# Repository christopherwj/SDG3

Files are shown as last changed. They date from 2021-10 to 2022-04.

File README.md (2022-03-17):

# SDG3 - Powered Speaker System - Happy Tunes

## What should I expect to find in this repo?

Here you can find all of the files related to Team 3's Senior Design Project

This includes: components, datasheets, simulations, source code and more!

## Who is on the team?

| Team Member | Field |
| :--- | :--- |
| Brian Ahlers | Electrical Engineer |
| Abraham Carranza | Computer Engineer |
| Kaitlyn Hamiter | Electrical Engineer |
| Christopher Johnson | Computer Engineer |
| Christopher Kihano  | Computer Engineer |

# Shortcuts

From here on you will find sections detailing different points of Team 3's progress, links to documents and Google Drive directories.

## Senior Design B

### Draw.io Diagrams

- <a href="https://drive.google.com/drive/folders/15kxVudf5h-fhxRucdEdU0__9-gUpvDf6?usp=sharing" target="_blank">Folder Directory</a>

### System Integration Testing
- [Report](https://docs.google.com/document/d/11B_BZgX_fD9LDzKS0TlejT2W-SY3xGZJBUBTwWxWOKQ/edit?usp=sharing)
- [Folder Directory](https://drive.google.com/drive/folders/19PX26QaqbOIaYj3eWc8ziYZd34B6GGTo?usp=sharing)

### Hardware Readiness

- [Report](https://docs.google.com/document/d/16WcHxM67mR_bLpcuLu_cNokmKFwlc5yR9lt_XE9QbTI/edit?usp=sharing)
- [Folder Directory](https://drive.google.com/drive/folders/1j9h-cdcIw9vPNtkVY1A0dE3LBrUp3cXq?usp=sharing)

### Firmware Readiness

- [Report](https://docs.google.com/document/d/1_yuX03Fo50LZgdDcOuhRRBqLqM6c0yxrTySWzuhtTM4/edit?usp=sharing)
- [Folder Directory](https://drive.google.com/drive/folders/1t-pBYhPXyJxyrI6B_gw4tiY_lfn7Jp15?usp=sharing)

### Team Labor Hours

- [Spreadsheet](https://docs.google.com/spreadsheets/d/12QhF0Mqp7NLQ3RBZjQvClqkk2QXMBvIy/edit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)
- [Folder Directory](https://drive.google.com/drive/folders/19Oa_INHHnQHptVcXvDggzD6vj_AUFLqU?usp=sharing)

## Senior Design A

### Draw.io Diagrams
- <a href="https://drive.google.com/drive/folders/15kxVudf5h-fhxRucdEdU0__9-gUpvDf6?usp=sharing" target="_blank">Folder Directory</a>

### System Description, Requirements, Validation

- [Report](https://docs.google.com/document/d/1fnrOCIRyJVDsxmta0oakdDbBKZW54d827w0m6OqQ11Q/edit?usp=sharing)
- [Folder Directory](https://drive.google.com/drive/folders/1NczNZ4O1j9Vx4oX85sgfJVTjJTQ-W3sH?usp=sharing)

### Risk Analysis

- [Report](https://drive.google.com/file/d/1sAik6q6ureZYssgTLGljBEHL8I2Zk15t/view?usp=sharing)
- [Folder Directory](https://drive.google.com/drive/folders/1NczNZ4O1j9Vx4oX85sgfJVTjJTQ-W3sH?usp=sharing)

### Prototype Activity

- [Report](https://drive.google.com/file/d/1stdICW6GUIWn7OOhUiIIFrHZ0VR0cqvk/view?usp=sharing)
- [Folder Directory](https://drive.google.com/drive/folders/1NczNZ4O1j9Vx4oX85sgfJVTjJTQ-W3sH?usp=sharing)

### Critical Design Review

- [Report](https://docs.google.com/presentation/d/1inkozGnM1z5_KCovr3mFNu3Ky42EYbz6ArtEo2gSImo/edit?usp=sharing)
- [Folder Directory](https://drive.google.com/drive/folders/1jWTyNvOkjsP8tEsv12XOycAalzhh8IQb?usp=sharing)

### Final Report

- [Report](https://docs.google.com/document/d/1AqZGzt35glmXr1-TCmBBXokeJKedO_IO3BRvOg3bReY/edit?usp=sharing)
- [Folder Directory](https://drive.google.com/drive/folders/1KJQUjUjOi4YFd6RUpi_W71EKjcTsQYTU?usp=sharing)

### Team Labor Hours

- [Spreadsheet](https://docs.google.com/spreadsheets/d/1y0pf061RG8TchD4RHMXZIr2CGgnv92BU/edit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)
- [Folder Directory](https://drive.google.com/drive/folders/1Dg6yo43kKn5nfYz5vgzlIPh3S6AtKxnr?usp=sharing)

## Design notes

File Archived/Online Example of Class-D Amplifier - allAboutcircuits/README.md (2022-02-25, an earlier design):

# All About Circuits - Class D Amplifier Example

In this directory you can find most, if not all, of the documents from the following webpage

- https://www.allaboutcircuits.com/projects/how-to-build-a-class-d-power-amplifier/

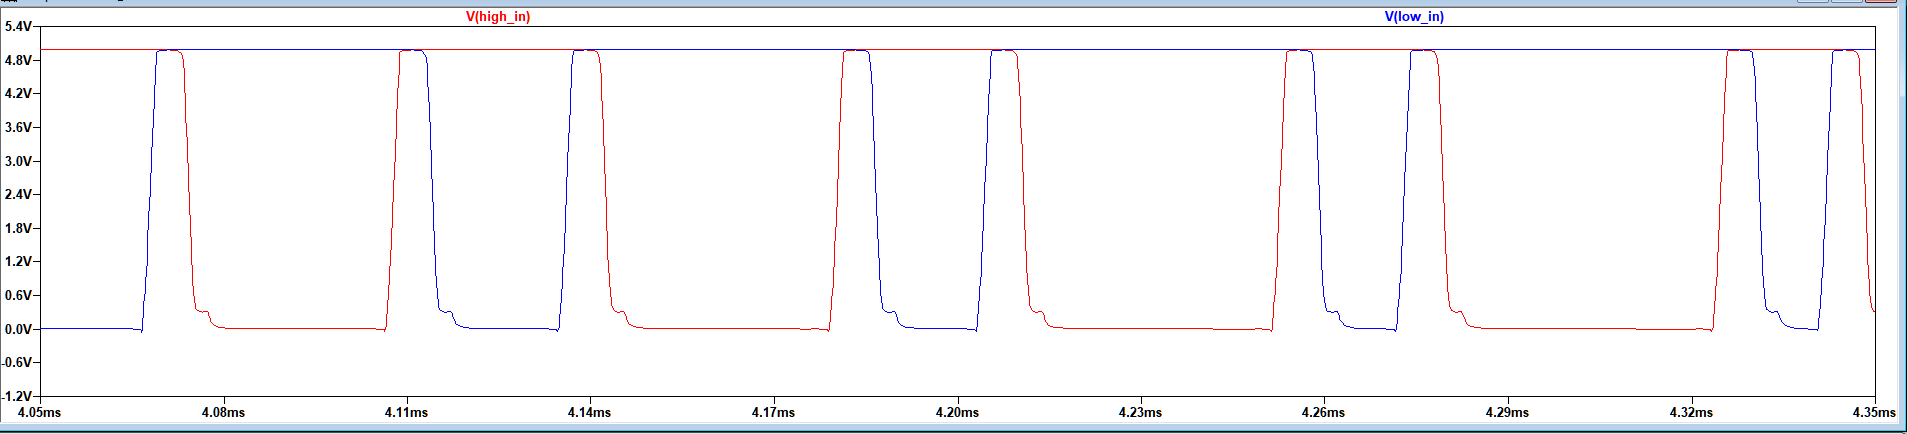
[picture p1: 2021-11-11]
Simulations/Senior Design A/Simulation Outputs/H_L_outLevelShifter.PNG

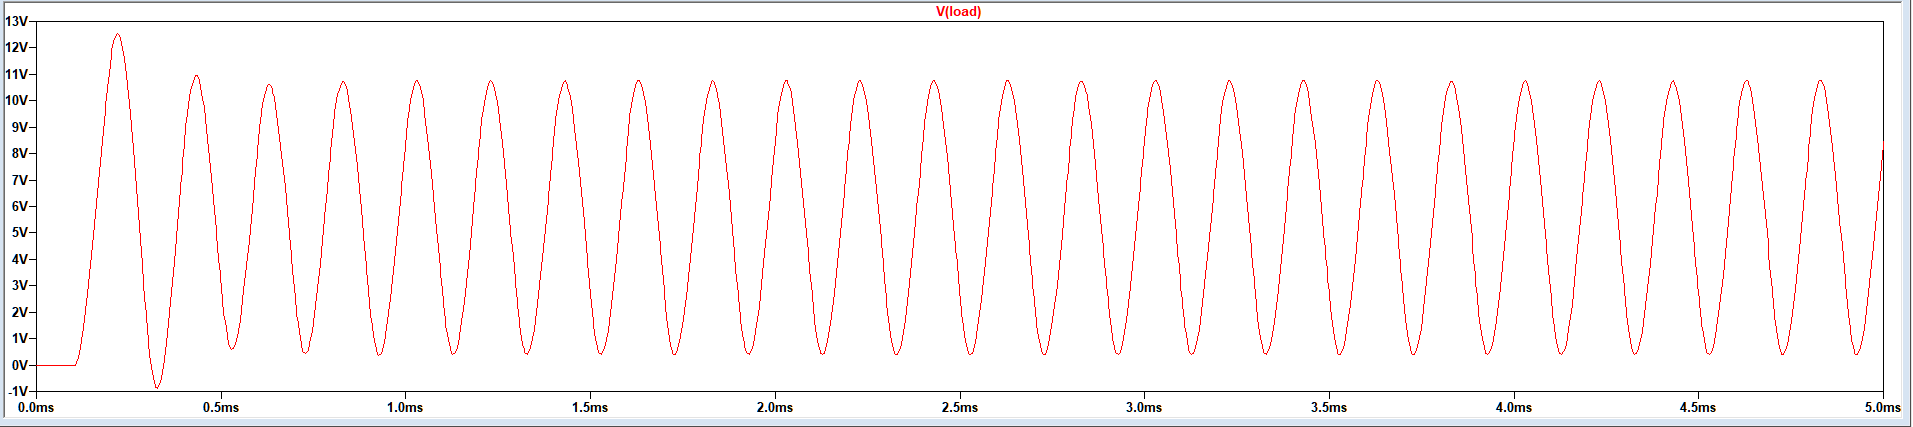
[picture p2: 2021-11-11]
Simulations/Senior Design A/Simulation Outputs/Output.PNG

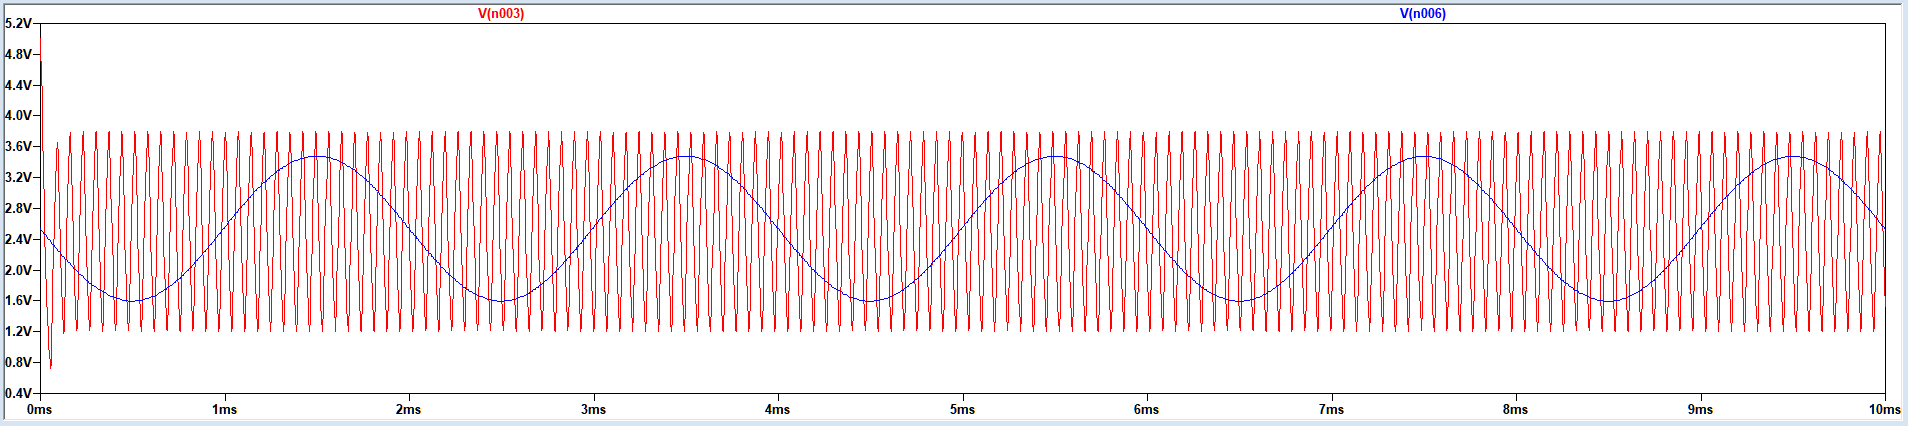
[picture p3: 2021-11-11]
Simulations/Senior Design A/Simulation Outputs/555vsBTAudio.PNG

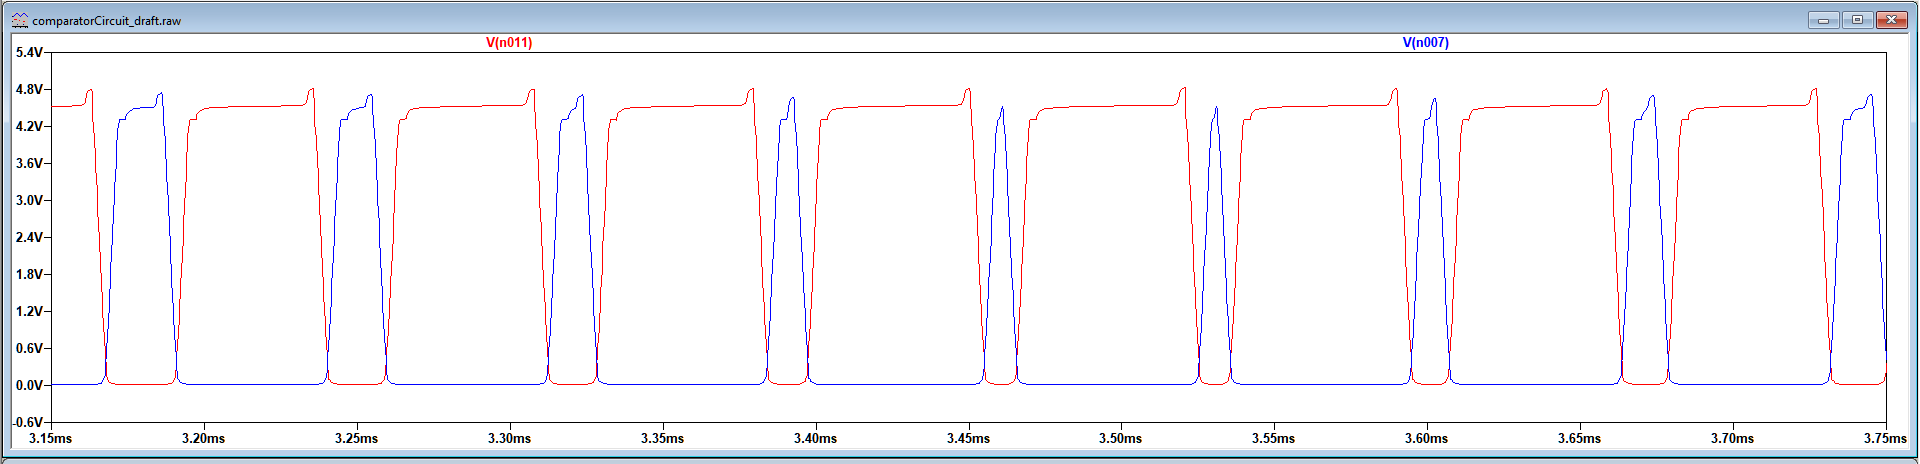
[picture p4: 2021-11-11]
Simulations/Senior Design A/Simulation Outputs/H_L_outofCOMP.PNG

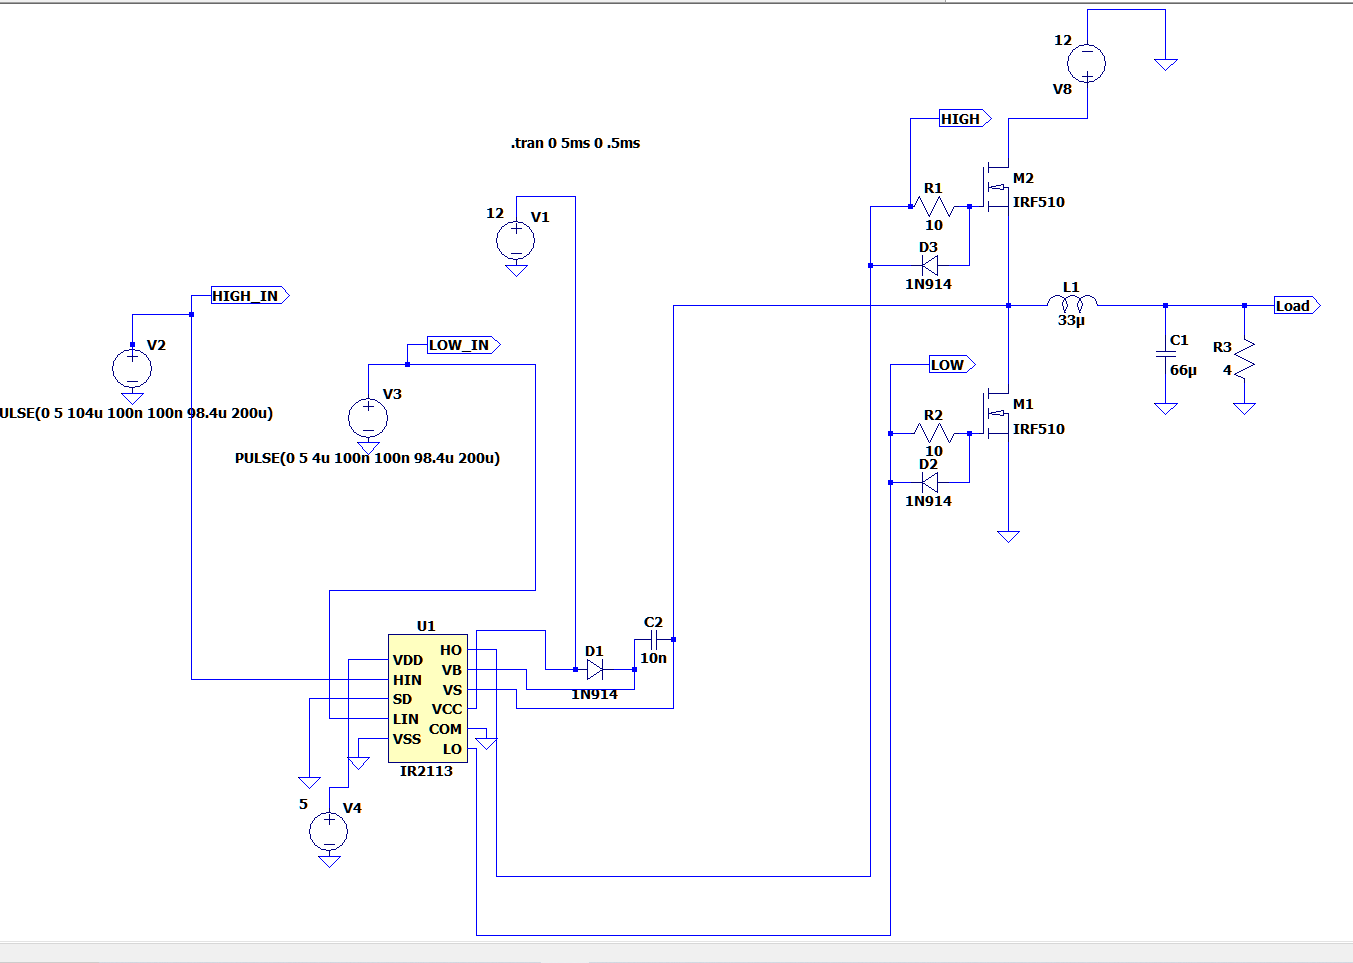
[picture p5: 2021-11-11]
Simulations/Senior Design A/Gate Driver Circuit 2/Gate Driver Circuit Schematic.PNG

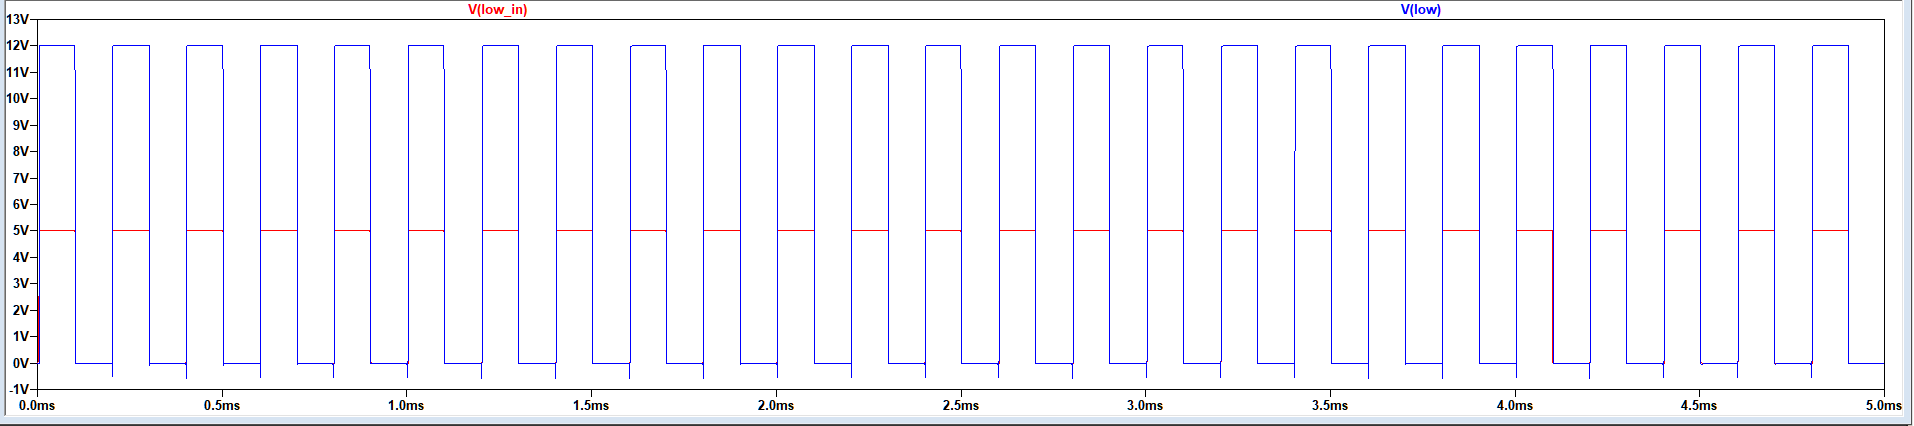
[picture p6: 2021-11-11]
Simulations/Senior Design A/Simulation Outputs/LinvsLout.PNG

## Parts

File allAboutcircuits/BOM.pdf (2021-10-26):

## BOM for Class-D amplifier

Nr. | Designator | Package | Quantity | Designation
1 | Q1,Q2 | TO-92_Inline_Narrow_Oval | 2 | 2N5401
2 | L1 | Inductor_T106-2 | 1 | 22uH
3 | R2 | Resistor_Horizontal_RM10mm | 1 | 2k2
4 | U4 | DIP-14_W7.62mm_LongPads | 1 | IR2110
5 | U3 | TO-220 | 1 | LM7805CT
6 | U2 | DIP-8_W7.62mm_LongPads | 1 | LM393AP
7 | U1 | DIP-8_W7.62mm_LongPads | 1 | LMC555CN
8 | R16,R15 | Resistor_Horizontal_RM10mm | 2 | 10
9 | R14,R13 | Resistor_Horizontal_RM10mm | 2 | 6.8k
10 | R11,R10 | Resistor_Horizontal_RM10mm | 2 | 10k
11 | R9,R8,R7,R6 | Resistor_Horizontal_RM10mm | 4 | 1k
12 | R5,R4 | Resistor_Horizontal_RM15mm | 2 | 1K-2W
13 | R3 | Resistor_Horizontal_RM10mm | 1 | 3.3k
14 | R1 | Resistor_Horizontal_RM10mm | 1 | 330k
15 | R12 | Resistor_Vertical_RM5mm | 1 | 10k
16 | Q5,Q4 | TO-220 | 2 | IRF540N
17 | Q3 | TO-220_Neutral123_Vertical | 1 | BD241C
18 | P1,P2,P3,P4,P5,P6Blade_Connector_6.3mm | 2 | -
19 | F2,F1 | Fuseholder5x20_horiz_open_inline | 2 | 6A
20 | D8,D7,D5,D4 | Diode_DO-35_SOD27_Horizontal_RM10 | 4 | 1N4148
21 | D6 | Diode_DO-41_SOD81_Horizontal_RM10 | 1 | MUR120
22 | D3 | Diode_DO-41_SOD81_Horizontal_RM10 | 1 | zener - 12V
23 | D2,D1 | Diode_DO-41_SOD81_Horizontal_RM10 | 2 | zener - 5V1
24 | C18,C15 | C_Rect_L18_W11_H19_P15 | 2 | 470nF
25 | C17,C13,C12 | C_Rect_L13_W4_P10 | 3 | 220nF
26 | C10 | C_Radial_D5_L11_P2 | 1 | 22uF
27 | C9,C8,C7,C6,C5,C4_Radial_D5_L11_P2 | 6 | 47uF
28 | C3,C1 | C_Rect_L7_W2_P5 | 2 | 1nF
29 | C2 | C_Radial_D5_L11_P2 | 1 | 10uF
30 | C11 | C_0805_HandSoldering | 1 | 100nF
31 | M3 | MountingHole_3.2mm_M3 | 4 | M3 Screw
Resistor values are in Ω. K = 1000. All are 1/4W except R4, R5 (2W)

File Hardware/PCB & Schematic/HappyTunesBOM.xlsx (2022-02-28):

ref | value5 | footprint | datasheet | lib | part | description | names | tstamps6 | tstamp | lib7 | part8 | description9 | docs | fp | field | name10 | num | name11 | type | alias | logical | uri | code | name12 | ref13 | pin
C1 | 0.05 uF | Capacitor_THT:C_Rect_L7.0mm_W2.5mm_P5.00mm | ~ | Device | C | Unpolarized capacitor | / | / | 62162C29
C10 | 22u | Capacitor_THT:C_Rect_L7.0mm_W2.5mm_P5.00mm | ~ | Device | C | Unpolarized capacitor | / | / | 6213681C
C11 | 5.6uF | Capacitor_THT:C_Rect_L7.0mm_W2.5mm_P5.00mm | ~ | Device | C | Unpolarized capacitor | / | / | 61A5E88D
C12 | 5.6uF | Capacitor_THT:C_Rect_L7.0mm_W2.5mm_P5.00mm | ~ | Device | C | Unpolarized capacitor | / | / | 62136830
C13 | 22uF | Capacitor_THT:C_Rect_L7.0mm_W2.5mm_P5.00mm | ~ | Device | C | Unpolarized capacitor | / | / | 621D758A
C2 | 220n | Capacitor_THT:C_Rect_L7.0mm_W2.5mm_P5.00mm | ~ | Device | C | Unpolarized capacitor | / | / | 61AAA34E
C3 | 250 uF | Capacitor_THT:C_Rect_L7.0mm_W2.5mm_P5.00mm | ~ | Device | CP | Polarized capacitor | / | / | 62158BF0
C4 | 220n | Capacitor_THT:C_Rect_L7.0mm_W2.5mm_P5.00mm | ~ | Device | C | Unpolarized capacitor | / | / | 621A181D
C5 | 220n | Capacitor_THT:C_Rect_L7.0mm_W2.5mm_P5.00mm | ~ | Device | C | Unpolarized capacitor | / | / | 621C33C0
C6 | 220n | Capacitor_THT:C_Rect_L7.0mm_W2.5mm_P5.00mm | ~ | Device | C | Unpolarized capacitor | / | / | 621C33D6
C7 | 220u | Capacitor_THT:C_Radial_D8.0mm_H7.0mm_P3.50mm | ~ | Device | CP | Polarized capacitor | / | / | 6210F666
C8 | 220u | Capacitor_THT:C_Radial_D8.0mm_H7.0mm_P3.50mm | ~ | Device | CP | Polarized capacitor | / | / | 62136920
C9 | 22u | Capacitor_THT:C_Rect_L7.0mm_W2.5mm_P5.00mm | ~ | Device | C | Unpolarized capacitor | / | / | 61A5D009
D1 | 1N914 | Diode_THT:D_DO-35_SOD27_P7.62mm_Horizontal | http://www.vishay.com/docs/85622/1n914.pdf | Diode | 1N914 | 100V 0.3A Small Signal Fast Switching Diode, DO-35 | / | / | 62281C4C
D2 | 1N914 | Diode_THT:D_DO-35_SOD27_P7.62mm_Horizontal | http://www.vishay.com/docs/85622/1n914.pdf | Diode | 1N914 | 100V 0.3A Small Signal Fast Switching Diode, DO-35 | / | / | 621C6EB2
D3 | 1N4007 | Diode_THT:D_DO-41_SOD81_P10.16mm_Horizontal | http://www.vishay.com/docs/88503/1n4001.pdf | Diode | 1N4007 | 1000V 1A General Purpose Rectifier Diode, DO-41 | / | / | 61A569FB
D4 | 1N4007 | Diode_THT:D_DO-41_SOD81_P10.16mm_Horizontal | http://www.vishay.com/docs/88503/1n4001.pdf | Diode | 1N4007 | 1000V 1A General Purpose Rectifier Diode, DO-41 | / | / | 621367F4
D5 | 1N4007 | Diode_THT:D_DO-41_SOD81_P10.16mm_Horizontal | http://www.vishay.com/docs/88503/1n4001.pdf | Diode | 1N4007 | 1000V 1A General Purpose Rectifier Diode, DO-41 | / | / | 61A580C3
D6 | 1N4007 | Diode_THT:D_DO-41_SOD81_P10.16mm_Horizontal | http://www.vishay.com/docs/88503/1n4001.pdf | Diode | 1N4007 | 1000V 1A General Purpose Rectifier Diode, DO-41 | / | / | 621367FE
H1 | MountingHole | MountingHole:MountingHole_2.2mm_M2 | ~ | Mechanical | MountingHole | Mounting Hole without connection | / | / | 621DD05A
H2 | MountingHole | MountingHole:MountingHole_2.2mm_M2 | ~ | Mechanical | MountingHole | Mounting Hole without connection | / | / | 621EA6A0
H3 | MountingHole | MountingHole:MountingHole_2.2mm_M2 | ~ | Mechanical | MountingHole | Mounting Hole without connection | / | / | 621DEFD8
H4 | MountingHole | MountingHole:MountingHole_2.2mm_M2 | ~ | Mechanical | MountingHole | Mounting Hole without connection | / | / | 621EB10E
J1 | AudioJack3 | Connector_Audio:Jack_3.5mm_CUI_SJ1-3533NG_Horizontal | ~ | Connector | AudioJack3 | Audio Jack, 3 Poles (Stereo / TRS) | / | / | 623336F4
J10 | TEST_LOW | Connector_Pin:Pin_D1.3mm_L11.0mm | ~ | Connector | Screw_Terminal_01x01 | Generic screw terminal, single row, 01x01, script generated (kicad-library-utils/schlib/autogen/connector/) | / | / | 61F99901
J11 | TEST_HIGH | Connector_Pin:Pin_D1.3mm_L11.0mm | ~ | Connector | Screw_Terminal_01x01 | Generic screw terminal, single row, 01x01, script generated (kicad-library-utils/schlib/autogen/connector/) | / | / | 621368BD
J12 | TEST_LOW | Connector_Pin:Pin_D1.3mm_L11.0mm | ~ | Connector | Screw_Terminal_01x01 | Generic screw terminal, single row, 01x01, script generated (kicad-library-utils/schlib/autogen/connector/) | / | / | 621368C9
J13 | TEST_Return | Connector_Pin:Pin_D1.3mm_L11.0mm | ~ | Connector | Screw_Terminal_01x01 | Generic screw terminal, single row, 01x01, script generated (kicad-library-utils/schlib/autogen/connector/) | / | / | 61F9C69A
J14 | TEST_Return | Connector_Pin:Pin_D1.3mm_L11.0mm | ~ | Connector | Screw_Terminal_01x01 | Generic screw terminal, single row, 01x01, script generated (kicad-library-utils/schlib/autogen/connector/) | / | / | 621368E1
J15 | TEST_OUTPUT | Connector_Pin:Pin_D1.3mm_L11.0mm | ~ | Connector | Screw_Terminal_01x01 | Generic screw terminal, single row, 01x01, script generated (kicad-library-utils/schlib/autogen/connector/) | / | / | 61F9A94A
J16 | TEST_OUTPUT | Connector_Pin:Pin_D1.3mm_L11.0mm | ~ | Connector | Screw_Terminal_01x01 | Generic screw terminal, single row, 01x01, script generated (kicad-library-utils/schlib/autogen/connector/) | / | / | 621368D5
J17 | Speaker | CustomFootprints:ScrewTerm | ~ | Connector | Screw_Terminal_01x02 | Generic screw terminal, single row, 01x02, script generated (kicad-library-utils/schlib/autogen/connector/) | / | / | 621368A6
J2 | BT Module | Connector_PinHeader_2.54mm:PinHeader_1x06_P2.54mm_Vertical | ~ | Connector | Conn_01x06_Female | Generic connector, single row, 01x06, script generated (kicad-library-utils/schlib/autogen/connector/) | / | / | 6237F84A
J3 | COMP_SINGAL | Connector_Pin:Pin_D1.3mm_L11.0mm | ~ | Connector | Screw_Terminal_01x01 | Generic screw terminal, single row, 01x01, script generated (kicad-library-utils/schlib/autogen/connector/) | / | / | 62377881
J4 | COMP_OUT_L | Connector_Pin:Pin_D1.3mm_L11.0mm | ~ | Connector | Screw_Terminal_01x01 | Generic screw terminal, single row, 01x01, script generated (kicad-library-utils/schlib/autogen/connector/) | / | / | 6237E9E9
J5 | COMP_OUT_H | Connector_Pin:Pin_D1.3mm_L11.0mm | ~ | Connector | Screw_Terminal_01x01 | Generic screw terminal, single row, 01x01, script generated (kicad-library-utils/schlib/autogen/connector/) | / | / | 62381A12
J6 | input | CustomFootprints:ScrewTerm | ~ | Connector | Screw_Terminal_01x02 | Generic screw terminal, single row, 01x02, script generated (kicad-library-utils/schlib/autogen/connector/) | / | / | 61AA1413
J7 | output_VCC | CustomFootprints:ScrewTerm | ~ | Connector | Screw_Terminal_01x02 | Generic screw terminal, single row, 01x02, script generated (kicad-library-utils/schlib/autogen/connector/) | / | / | 61AB4357
J8 | output_5V | CustomFootprints:ScrewTerm | ~ | Connector | Screw_Terminal_01x02 | Generic screw terminal, single row, 01x02, script generated (kicad-library-utils/schlib/autogen/connector/) | / | / | 61AB4B41
J9 | TEST_HIGH | Connector_Pin:Pin_D1.3mm_L11.0mm | ~ | Connector | Screw_Terminal_01x01 | Generic screw terminal, single row, 01x01, script generated (kicad-library-utils/schlib/autogen/connector/) | / | / | 61F96EB2
L1 | 45 uH | Inductor_THT:L_CommonMode_Toroid_Vertical_L24.0mm_W16.3mm_Px10.16mm_Py20.32mm_muRATA_5200 | ~ | pspice | INDUCTOR | Inductor symbol for simulation only | / | / | 61A5DF8E
L2 | 45 uH | Inductor_THT:L_CommonMode_Toroid_Vertical_L24.0mm_W16.3mm_Px10.16mm_Py20.32mm_muRATA_5200 | https://www.murata-ps.com/pub/data/magnetics/kmp_3300.pdf | pspice | INDUCTOR | Inductor symbol for simulation only | / | / | 62136826
Q1 | IRF540N | Package_TO_SOT_THT:TO-220-3_Vertical | http://www.irf.com/product-info/datasheets/data/irf540n.pdf | Transistor_FET | IRF540N | 33A Id, 100V Vds, HEXFET N-Channel MOSFET, TO-220 | / | / | 62A0BE19
Q2 | IRF540N | Package_TO_SOT_THT:TO-220-3_Vertical | http://www.irf.com/product-info/datasheets/data/irf540n.pdf | Transistor_FET | IRF540N | 33A Id, 100V Vds, HEXFET N-Channel MOSFET, TO-220 | / | / | 62AE0A06
Q3 | IRF540N | Package_TO_SOT_THT:TO-220-3_Vertical | http://www.irf.com/product-info/datasheets/data/irf540n.pdf | Transistor_FET | IRF540N | 33A Id, 100V Vds, HEXFET N-Channel MOSFET, TO-220 | / | / | 61A7438A
Q4 | IRF540N | Package_TO_SOT_THT:TO-220-3_Vertical | http://www.irf.com/product-info/datasheets/data/irf540n.pdf | Transistor_FET | IRF540N | 33A Id, 100V Vds, HEXFET N-Channel MOSFET, TO-220 | / | / | 61A713D5
Q5 | IRF540N | Package_TO_SOT_THT:TO-220-3_Vertical | http://www.irf.com/product-info/datasheets/data/irf540n.pdf | Transistor_FET | IRF540N | 33A Id, 100V Vds, HEXFET N-Channel MOSFET, TO-220 | / | / | 6213686C
Q6 | IRF540N | Package_TO_SOT_THT:TO-220-3_Vertical | http://www.irf.com/product-info/datasheets/data/irf540n.pdf | Transistor_FET | IRF540N | 33A Id, 100V Vds, HEXFET N-Channel MOSFET, TO-220 | / | / | 621368F0
R1 | 10k | Resistor_THT:R_Axial_DIN0204_L3.6mm_D1.6mm_P7.62mm_Horizontal | ~ | Device | R | Resistor | / | / | 62A0984B
R10 | 1k | Resistor_THT:R_Axial_DIN0204_L3.6mm_D1.6mm_P7.62mm_Horizontal | ~ | Device | R | Resistor | / | / | 62365616
R11 | 10 | Resistor_THT:R_Axial_DIN0204_L3.6mm_D1.6mm_P7.62mm_Horizontal | ~ | Device | R | Resistor | / | / | 61A58DF0
R12 | 10 | Resistor_THT:R_Axial_DIN0204_L3.6mm_D1.6mm_P7.62mm_Horizontal | ~ | Device | R | Resistor | / | / | 62136808
R13 | 10 | Resistor_THT:R_Axial_DIN0204_L3.6mm_D1.6mm_P7.62mm_Horizontal | ~ | Device | R | Resistor | / | / | 61A5A87A
R14 | 10 | Resistor_THT:R_Axial_DIN0204_L3.6mm_D1.6mm_P7.62mm_Horizontal | ~ | Device | R | Resistor | / | / | 62136812
R15 | 10k | Resistor_THT:R_Axial_DIN0204_L3.6mm_D1.6mm_P7.62mm_Horizontal | ~ | Device | R | Resistor | / | / | 621095E5
R16 | 10k | Resistor_THT:R_Axial_DIN0204_L3.6mm_D1.6mm_P7.62mm_Horizontal | ~ | Device | R | Resistor | / | / | 62136905
R17 | 10k | Resistor_THT:R_Axial_DIN0204_L3.6mm_D1.6mm_P7.62mm_Horizontal | ~ | Device | R | Resistor | / | / | 62108A44
R18 | 10k | Resistor_THT:R_Axial_DIN0204_L3.6mm_D1.6mm_P7.62mm_Horizontal | ~ | Device | R | Resistor | / | / | 621368FA
R2 | 10k | Resistor_THT:R_Axial_DIN0204_L3.6mm_D1.6mm_P7.62mm_Horizontal | ~ | Device | R | Resistor | / | / | 6216B860
R3 | 10k | Resistor_THT:R_Axial_DIN0204_L3.6mm_D1.6mm_P7.62mm_Horizontal | ~ | Device | R | Resistor | / | / | 6216AD7A
R4 | 10k | Resistor_THT:R_Axial_DIN0204_L3.6mm_D1.6mm_P7.62mm_Horizontal | ~ | Device | R | Resistor | / | / | 62326AF8
R5 | 10k | Resistor_THT:R_Axial_DIN0204_L3.6mm_D1.6mm_P7.62mm_Horizontal | ~ | Device | R | Resistor | / | / | 623227F2
R6 | 10k | Resistor_THT:R_Axial_DIN0204_L3.6mm_D1.6mm_P7.62mm_Horizontal | ~ | Device | R | Resistor | / | / | 62AB1896
R7 | 10k | Resistor_THT:R_Axial_DIN0204_L3.6mm_D1.6mm_P7.62mm_Horizontal | ~ | Device | R | Resistor | / | / | 62ADFF7C
R8 | 10 | Resistor_THT:R_Axial_DIN0204_L3.6mm_D1.6mm_P7.62mm_Horizontal | ~ | Device | R | Resistor | / | / | 6216F78B
R9 | 10k | Resistor_THT:R_Axial_DIN0204_L3.6mm_D1.6mm_P7.62mm_Horizontal | ~ | Device | R | Resistor | / | / | 62AE0A1B
RV1 | 10k_POT_TRIM_US | Potentiometer_THT:Potentiometer_Alps_RK09K_Single_Horizontal | ~ | Device | R_POT_TRIM_US | Trim-potentiometer, US symbol | / | / | 621F797F
RV2 | 10k_POT_TRIM_US | Potentiometer_THT:Potentiometer_Alps_RK09K_Single_Horizontal | ~ | Device | R_POT_TRIM_US | Trim-potentiometer, US symbol | / | / | 621F56DD
SW1 | SW_SPDT_MSM | Button_Switch_THT:SW_CuK_OS102011MA1QN1_SPDT_Angled | ~ | Switch | SW_SPDT_MSM | Switch, single pole double throw, center OFF position | / | / | 62273C1A
SW2 | SW_Push_DPDT | Button_Switch_THT:SW_CuK_JS202011AQN_DPDT_Angled | ~ | Switch | SW_Push_DPDT | Momentary Switch, dual pole double throw | / | / | 6258EC3B
SW3 | SW_SPDT_MSM | Button_Switch_THT:SW_CuK_OS102011MA1QN1_SPDT_Angled | ~ | Switch | SW_SPDT_MSM | Switch, single pole double throw, center OFF position | / | / | 6237C367
U1 | LM7805_TO220 | Package_TO_SOT_THT:TO-220-3_Vertical | https://www.onsemi.cn/PowerSolutions/document/MC7800-D.PDF | Regulator_Linear | LM7805_TO220 | Positive 1A 35V Linear Regulator, Fixed Output 5V, TO-220 | / | / | 61A50F17
U2 | LM7810_TO220 | Package_TO_SOT_THT:TO-220-3_Vertical | https://www.onsemi.cn/PowerSolutions/document/MC7800-D.PDF | Regulator_Linear | LM7810_TO220 | Positive 1A 35V Linear Regulator, Fixed Output 10V, TO-220 | / | / | 626785CD
U3 | LM386 | Package_DIP:DIP-8_W7.62mm_Socket | http://www.ti.com/lit/ds/symlink/lm386.pdf | Amplifier_Audio | LM386 | Low Voltage Audio Power Amplifier, DIP-8/SOIC-8/SSOP-8 | / | / | 62152F78
U5 | IR2113 | Package_DIP:DIP-14_W7.62mm_Socket | https://www.infineon.com/dgdl/ir2110.pdf?fileId=5546d462533600a4015355c80333167e | Driver_FET | IR2113 | High and Low Side Driver, 600V, 2.0/2.0A, PDIP-14 | / | / | 621367D6
XA1 | Arduino_Due_Shield | Arduino:Arduino_Due_Shield | https://store.arduino.cc/arduino-due | GateDriver-rescue | Arduino_Due_Shield-arduino |  | / | / | 621319E3

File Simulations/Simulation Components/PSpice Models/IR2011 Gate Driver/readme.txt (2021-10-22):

##########################################################################################
## Simulation model of IR2011 Level 1 for SIMetrix version 8.3g or higher
##########################################################################################

--------------------------------------------------------------------------------
1. Changelog
--------------------------------------------------------------------------------
VER    | BY                       | DATE          | OBS                         
--------------------------------------------------------------------------------
01.00  | MA                       | 2020-09-11    | created    (*1)
--------------------------------------------------------------------------------

(*1) 
Simulation model of IR2011 Level 1 for SIMetrix version 8.3g or higher
Template performance : 
  - Static Electrical Characteristics and Dynamic Electrical Characteristics 
    are modeled with the typical values from the datasheet.
  - Temperature effects are not modeled
The following features have been modeled :
  - Switching Characteristics such as propagation delay, peak/mean currents
  - Undervoltage lockout 

--------------------------------------------------------------------------------
2. Supported platform
--------------------------------------------------------------------------------
This model has been successfully tested with the following software:
- SIMetrix 8.3g or newer versions

--------------------------------------------------------------------------------
3. Structure of the delivery package
--------------------------------------------------------------------------------
The delivery package contains the following:

	\Documentation\GettingStarted.pdf         : guidance on how to get started with the attached behavioral model
	\Documentation\Disclaimer.pdf             : Infineon’s model terms of use
	\Model\IR2011.lib                         : model lib file
	\Model\IR2011.sxslb                       : schematic symbol for the lib
	\Model\DEMO_TESTBENCH.sxsch               : demo testbench provided together with the model 
	\Model\IGBT_650V_TRENCHSTOP5_F5_L1.lib    : Infineon's IGBT model
	\Model\IGBT_650V_TRENCHSTOP5_F5_L1.sxslb  : Infineon's IGBT symbol for schematic
	\Model\results                            : some screenshots with the demo testbench and results
	
--------------------------------------------------------------------------------
4. Infineon contact and support
--------------------------------------------------------------------------------
support@infineon.com

--------------------------------------------------------------------------------
5. Disclaimer
--------------------------------------------------------------------------------

INFINEON’S MODEL TERMS OF USE

BY DOWNLOADING AND/OR USING THIS INFINEON MODEL (“MODEL”), THE USER (INCLUDING YOU) 
AGREES TO BE BOUND BY THE TERMS OF USE HERE STATED. IF USER DOES NOT AGREE TO ALL TERMS OF
USE HERE STATED, USER SHALL NOT DOWNLOAD, USE OR COPY THE MODEL BUT IMMEDIATELY DELETE 
IT (TO THE EXTENT THAT IT WAS DOWNLOADED ALREADY).

1. SCOPE OF USE
1.1 Any use of this Model provided by Infineon Technologies AG is subject to these Terms of Use.
1.2 This Model, provided by Infineon, does not fully represent all of the specifications and
operating characteristics of the product to which this Model relates.
1.3 This Model only describes the characteristics of a typical product. In all cases, the current data
sheet information for a given product is the final design guideline and the only actual 
performance specification. Although this Model can be a useful tool to evaluate the product 
performance, it cannot simulate the exact product performance under all conditions and it is 
also not intended to replace bread-boarding for final verification.

2. IMPORTANT NOTICE
2.1 Infineon Technologies AG (“Infineon”) is not and cannot be aware of the specific application of 
the Infineon’s Model by User. However, Model may from time to time be used by User in potentially 
harmful and/or life-endangering applications such as traffic, logistic, medical, nuclear or military a
pplications or in other applications where failure of the Model may predictably cause damage to 
persons’ life or health or to property (hereinafter "Critical Applications").
2.2 User acknowledges that Infineon has not specifically designed or qualified the Model for 
Critical Applications that the Model may contain errors and bugs and that User is required to 
qualify the Model for Critical Applications pursuant to the applicable local quality, safety and 
legal requirements before permitting or giving access to any such use.

3. CONFIDENTIAL INFORMATION
User shall treat ideas, concepts and information incorporated in the Model, the documentation and 
the content of this Terms of Use (together hereinafter "Confidential Information") confidential, not 
disclose it to any third party unless otherwise agreed in writing between User and Infineon, not use 
it for any other purposes than using the Model for simulation and testing purposes only.

4. WARRANTY
4.1 User acknowledges that the Model is provided by Infineon under this Terms of Use is provided free 
of charge and "AS IS" without any warranty or liability of any kind and Infineon hereby expressly 
disclaims any warranties or representations, whether express, implied, statutory or otherwise, 
including but not limited to warranties of workmanship, merchantability, fitness for a particular 
purpose, defects in the Model, or non-infringement of third parties intellectual property rights.
4.2 Infineon reserves the right to make corrections, deletions, modifications, enhancements, 
improvements and other changes to the Model at any time or to move or discontinue any Model without notice.

5. LIABILITY
5.1 Nothing in this Terms of Use shall limit or exclude Infineon's liability under mandatory liability 
laws, for injuries to life, body or health, for fraudulent concealment of defects in the software, or 
in cases of Infineon's intentional misconduct or gross negligence.
5.2 Without prejudice to Sections 5.1, in cases of Infineon's slight negligent breach of obligations 
that restrict essential rights or duties arising from the nature of this Terms of Use in a way that 
there is a risk of non-achievement of the purpose of this Terms of Use or of an obligation whose observance
User regularly may trust in and whereas compliance with only makes proper execution of this Terms 
of Use possible, Infineon's liability shall be limited to the typically, foreseeable damage.
5.3 Without prejudice to Sections 8.1 and 8.2, Infineon's liability under this Agreement shall be excluded in all 
other cases.

6. EXPORT REGULATIONS
The User shall comply with all applicable national and international laws and regulations, in 
particular the applicable export control regulations and sanction programs. The User also agrees 
not to export, re-export or transfer any software or technology developed with or using information, 
software or technology offered by Infineon, in violation of any applicable laws or regulations of 
the competent authorities. Further, the User shall neither use any products, information, software 
and technology offered by Infineon in or in connection with nuclear technology or weapons of mass 
destruction (nuclear, biological or chemical) and carriers thereof nor supply military consignees.

7. TERMINATION OF USE PERMIT
If the User violates these Terms of Use, such User’s permit to use this Model terminates automatically. 
In addition, Infineon may terminate the User’s permit to use this Model at its discretion and at 
any time regardless of any violation of these Terms of Use. In any of the foregoing events, the User 
is obliged to immediately destroy any content that has been downloaded or printed from Infineon’s website.

8. MISCELLANEOUS
8.1 These Terms of Use are subject to the laws of the Federal Republic of Germany with the exception 
of the United Nations on Purchase Contracts on the International Sale of Goods dated April 11, 1980 (CISG). 
The exclusive place of jurisdiction is Munich, Germany.
8.2 Should any provision in these Terms of Use be or become invalid, the validity of all other 
provisions or agreements shall remain unaffected thereby.

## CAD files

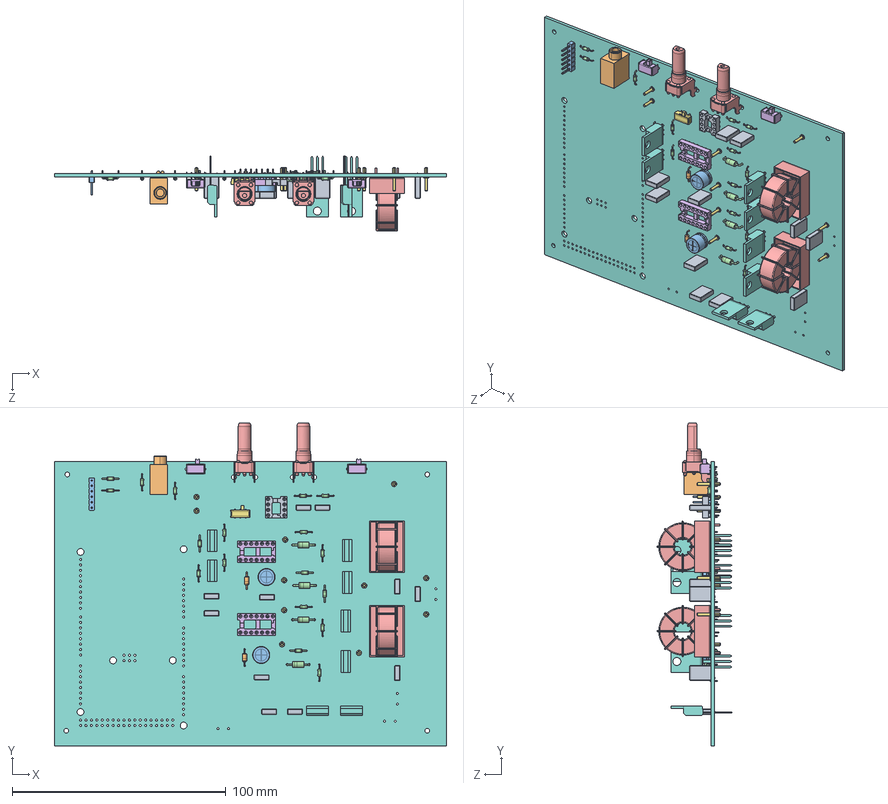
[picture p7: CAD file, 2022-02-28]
Hardware/3D_Models_Solidworks/GateDriver.SLDASM
183.5 x 151.0 x 35.0 mm
SOLID.step x 11
SOLID-0.step
SOLID-1.step
SOLID-2.step x 18
COMPOUND.step x 2
COMPOUND-3.step x 2
SOLID-4.step
SOLID-5.step x 8
SOLID-6.step
COMPOUND-7.step x 2
SOLID-8.step x 2
SOLID-9.step x 4
COMPOUND-10.step x 2
SOLID-11.step x 2
SOLID-12.step x 11
_autosave-GateDriver PCB.step

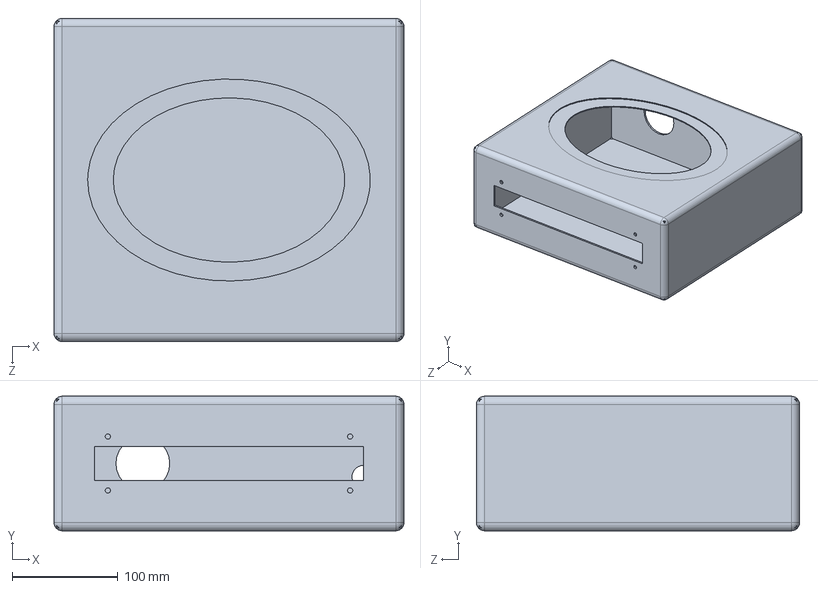
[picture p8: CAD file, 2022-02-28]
Hardware/3D_Models_Solidworks/SpeakerBox.SLDPRT
330.2 x 127.0 x 304.8 mm

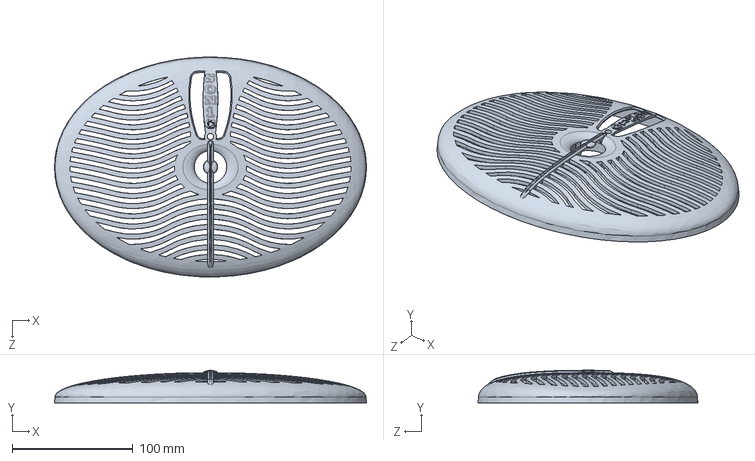
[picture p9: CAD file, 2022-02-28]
Hardware/3D_Models_Solidworks/User Library-6x9 marine speaker-grille.sldprt
258.6 x 27.0 x 182.3 mm

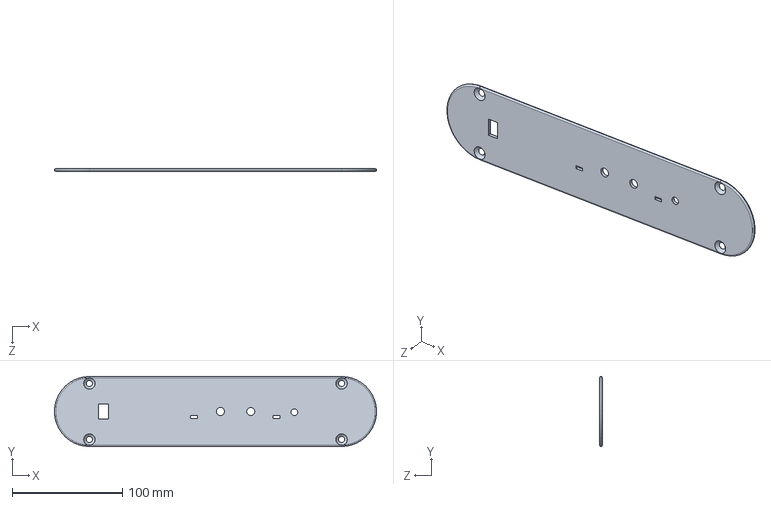
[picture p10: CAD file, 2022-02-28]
Hardware/3D_Models_Solidworks/FacePlate.SLDPRT
291.9 x 63.5 x 2.54 mm

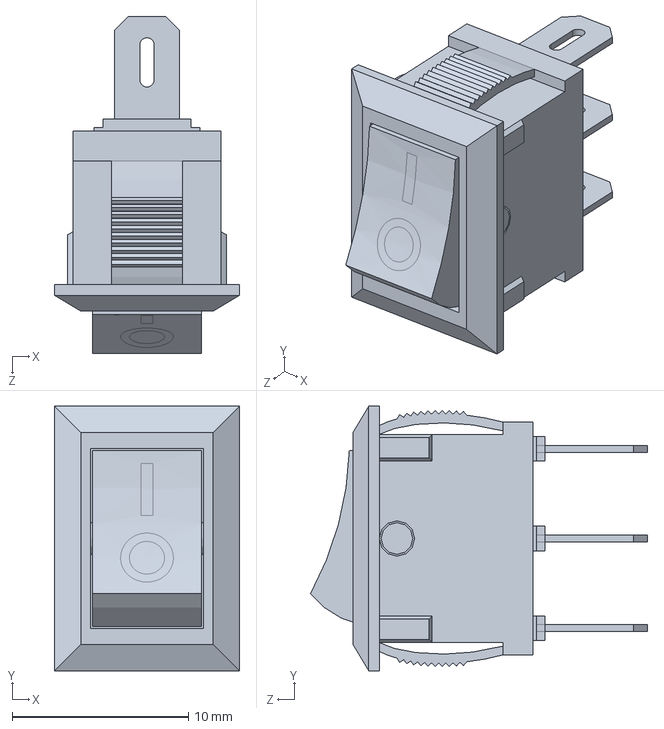
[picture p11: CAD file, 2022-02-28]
Hardware/3D_Models_Solidworks/User Library-KCD11-A-101O11RB.sldprt
10.5 x 15.0 x 19.1 mm

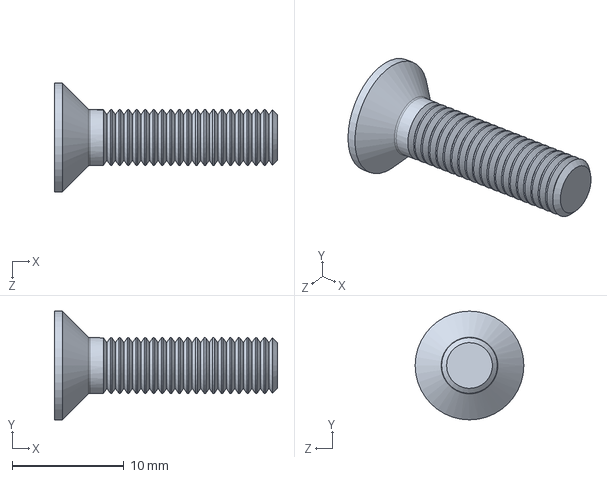
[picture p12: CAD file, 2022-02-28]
Hardware/3D_Models_Solidworks/M5 x 20 csk machine screw.SLDPRT
20.0 x 9.75 x 9.75 mm

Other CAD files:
Hardware/3D_Models_Solidworks/FacePlateSheet.SLDDRW
Hardware/3D_Models_Solidworks/SpeakerBoxSheet.SLDDRW

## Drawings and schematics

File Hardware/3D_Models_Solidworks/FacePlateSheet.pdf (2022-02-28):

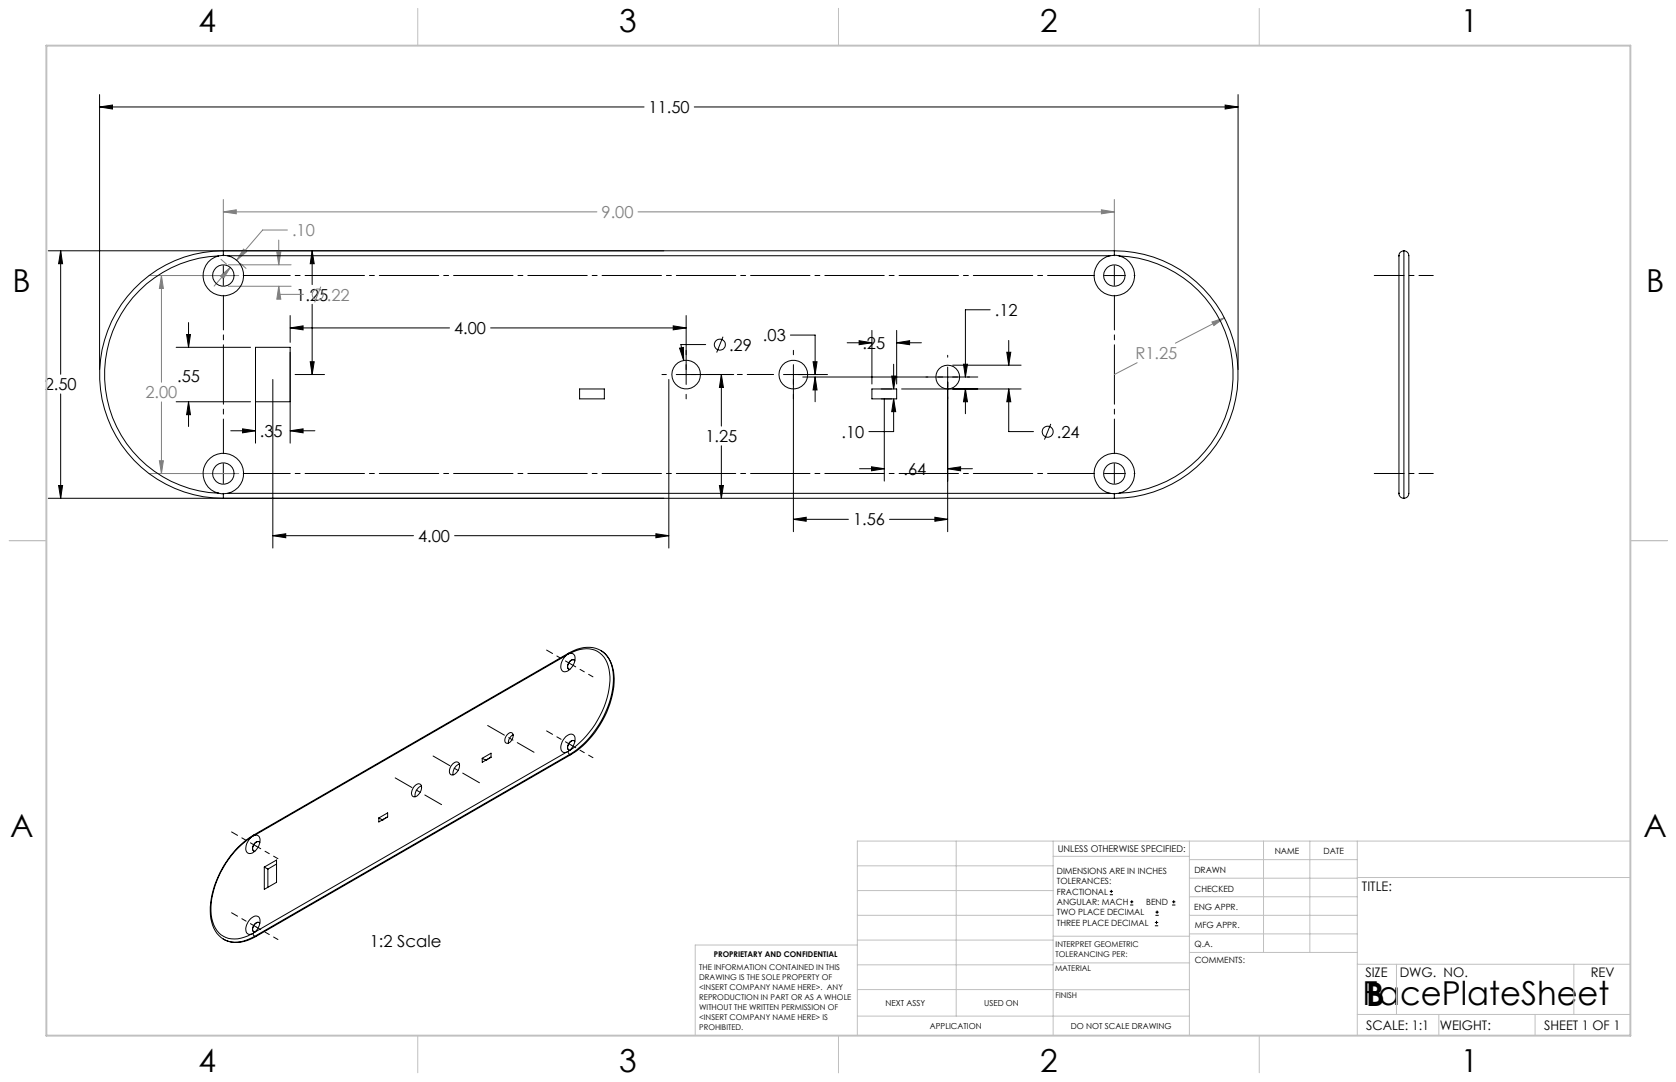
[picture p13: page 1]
1:2 Scale

UNLESS OTHERWISE SPECIFIED: | | NAME | DATE
DIMENSIONS ARE IN INCHES TOLERANCES: FRACTIONAL ANGULAR: MACH BEND TWO PLACE DECIMAL THREE PLACE DECIMAL | DRAWN

CHECKED | | | TITLE:

ENG APPR.
MFG APPR.

INTERPRET GEOMETRIC TOLERANCING PER: | Q.A.
MATERIAL | | SIZE FacePlateSheet B | DWG. NO. | REV

PROPRIETARY AND CONFIDENTIAL
THE INFORMATION CONTAINED IN THIS
DRAWING IS THE SOLE PROPERTY OF
<INSERT COMPANY NAME HERE>. ANY
REPRODUCTION IN PART OR AS A WHOLE
WITHOUT THE WRITTEN PERMISSION OF
<INSERT COMPANY NAME HERE> IS
PROHIBITED.

NEXT ASSY | USED ON | FINISH

APPLICATION | DO NOT SCALE DRAWING | | SCALE: 1:1 | WEIGHT: | SHEET 1 OF 1

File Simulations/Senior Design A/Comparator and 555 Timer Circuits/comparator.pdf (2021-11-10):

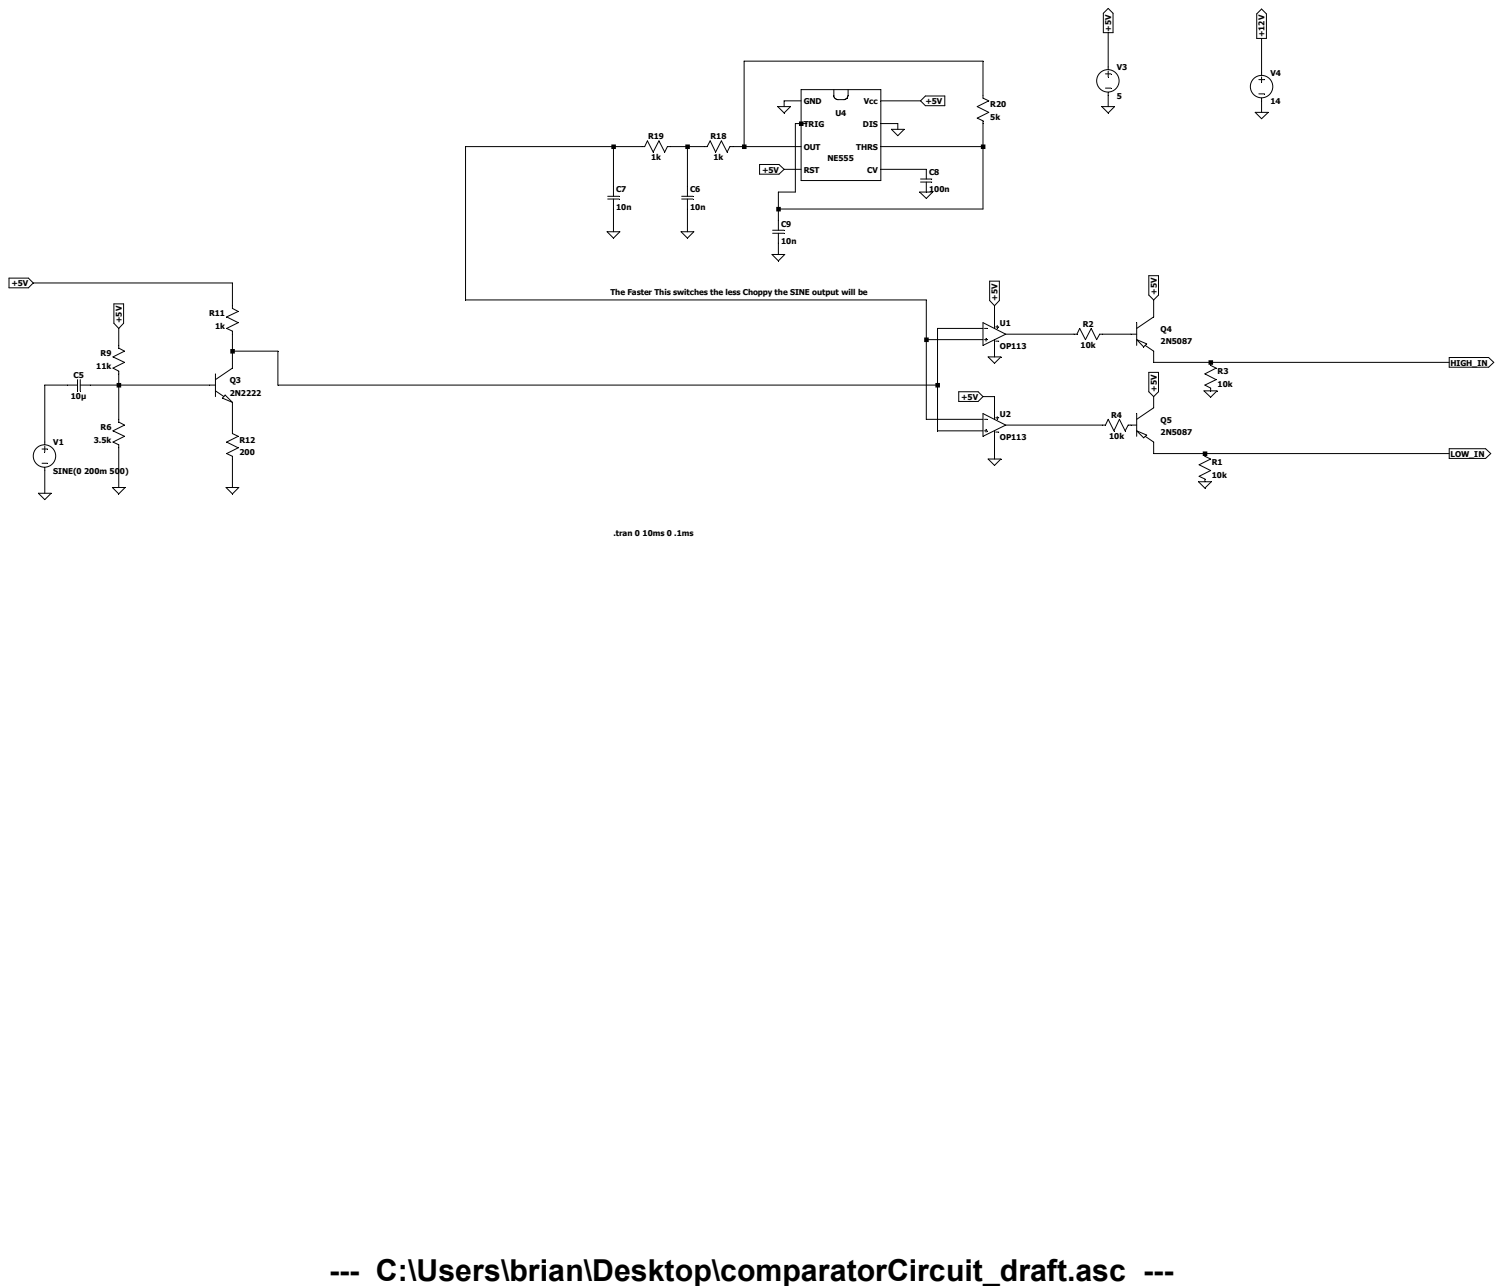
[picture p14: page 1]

The Faster This switches the less Choppy the SINE output will be

--- C:\Users\brian\Desktop\comparatorCircuit_draft.asc ---

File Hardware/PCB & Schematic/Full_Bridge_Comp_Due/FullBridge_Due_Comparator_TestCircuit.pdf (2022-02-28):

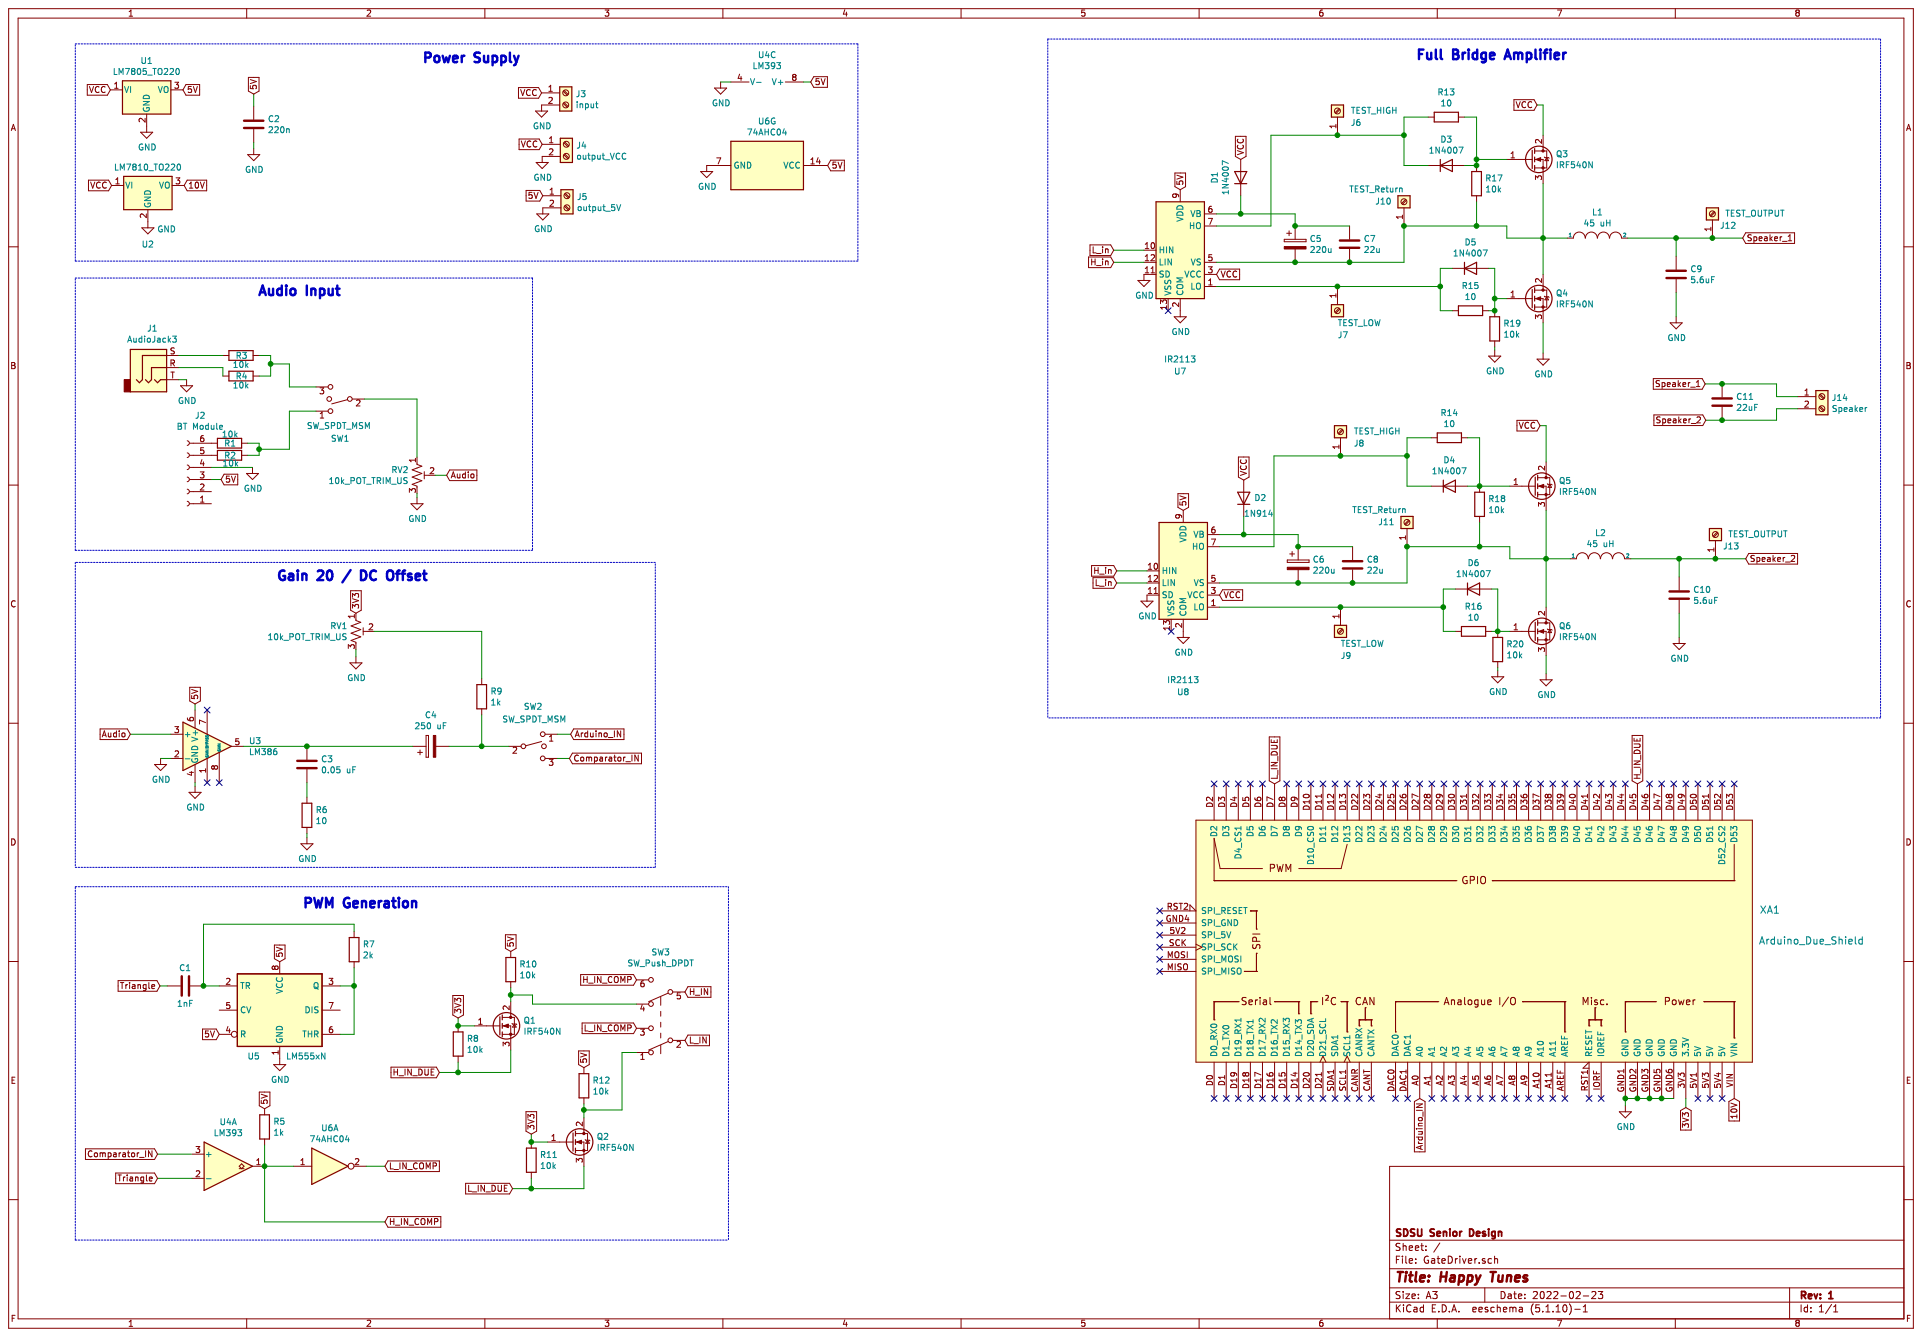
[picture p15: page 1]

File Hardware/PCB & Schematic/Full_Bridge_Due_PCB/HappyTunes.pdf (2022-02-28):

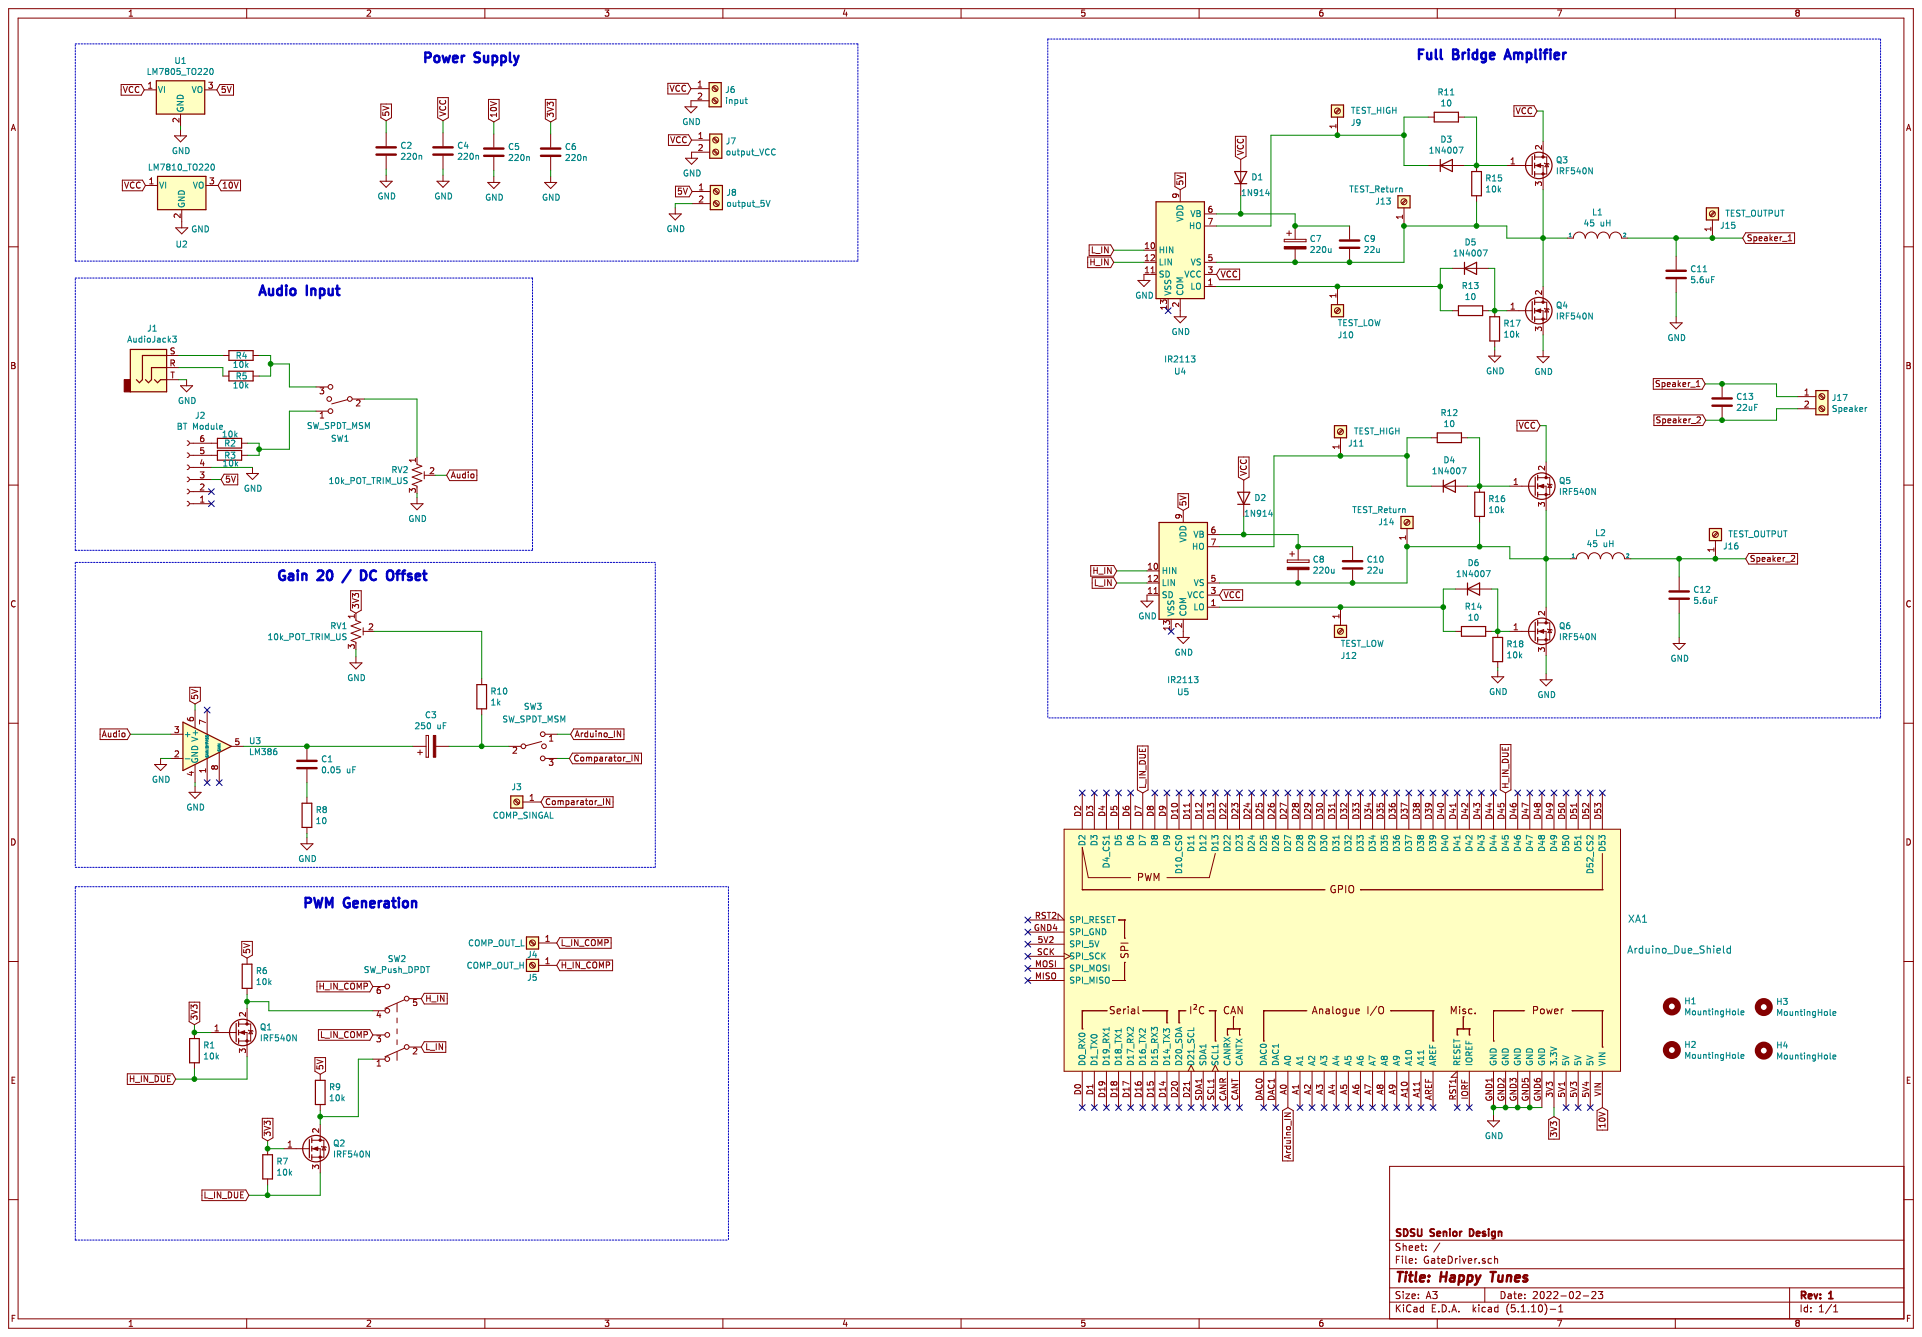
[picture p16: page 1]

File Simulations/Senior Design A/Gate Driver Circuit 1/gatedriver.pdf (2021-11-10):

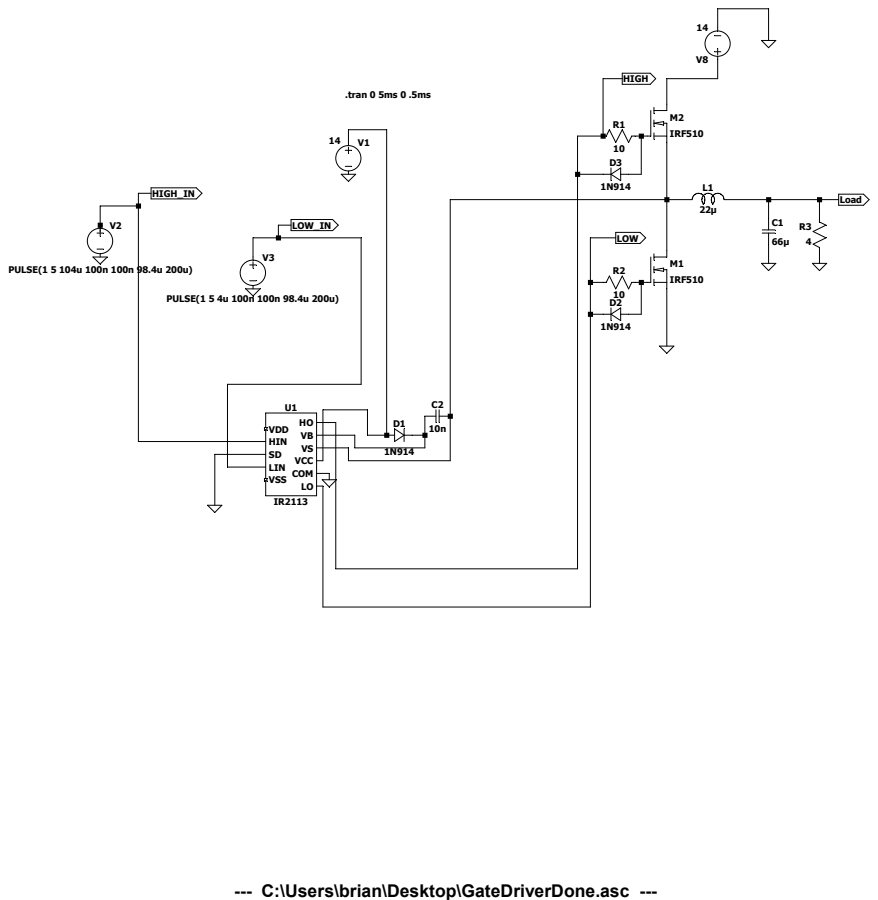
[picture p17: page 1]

--- C:\Users\brian\Desktop\GateDriverDone.asc ---

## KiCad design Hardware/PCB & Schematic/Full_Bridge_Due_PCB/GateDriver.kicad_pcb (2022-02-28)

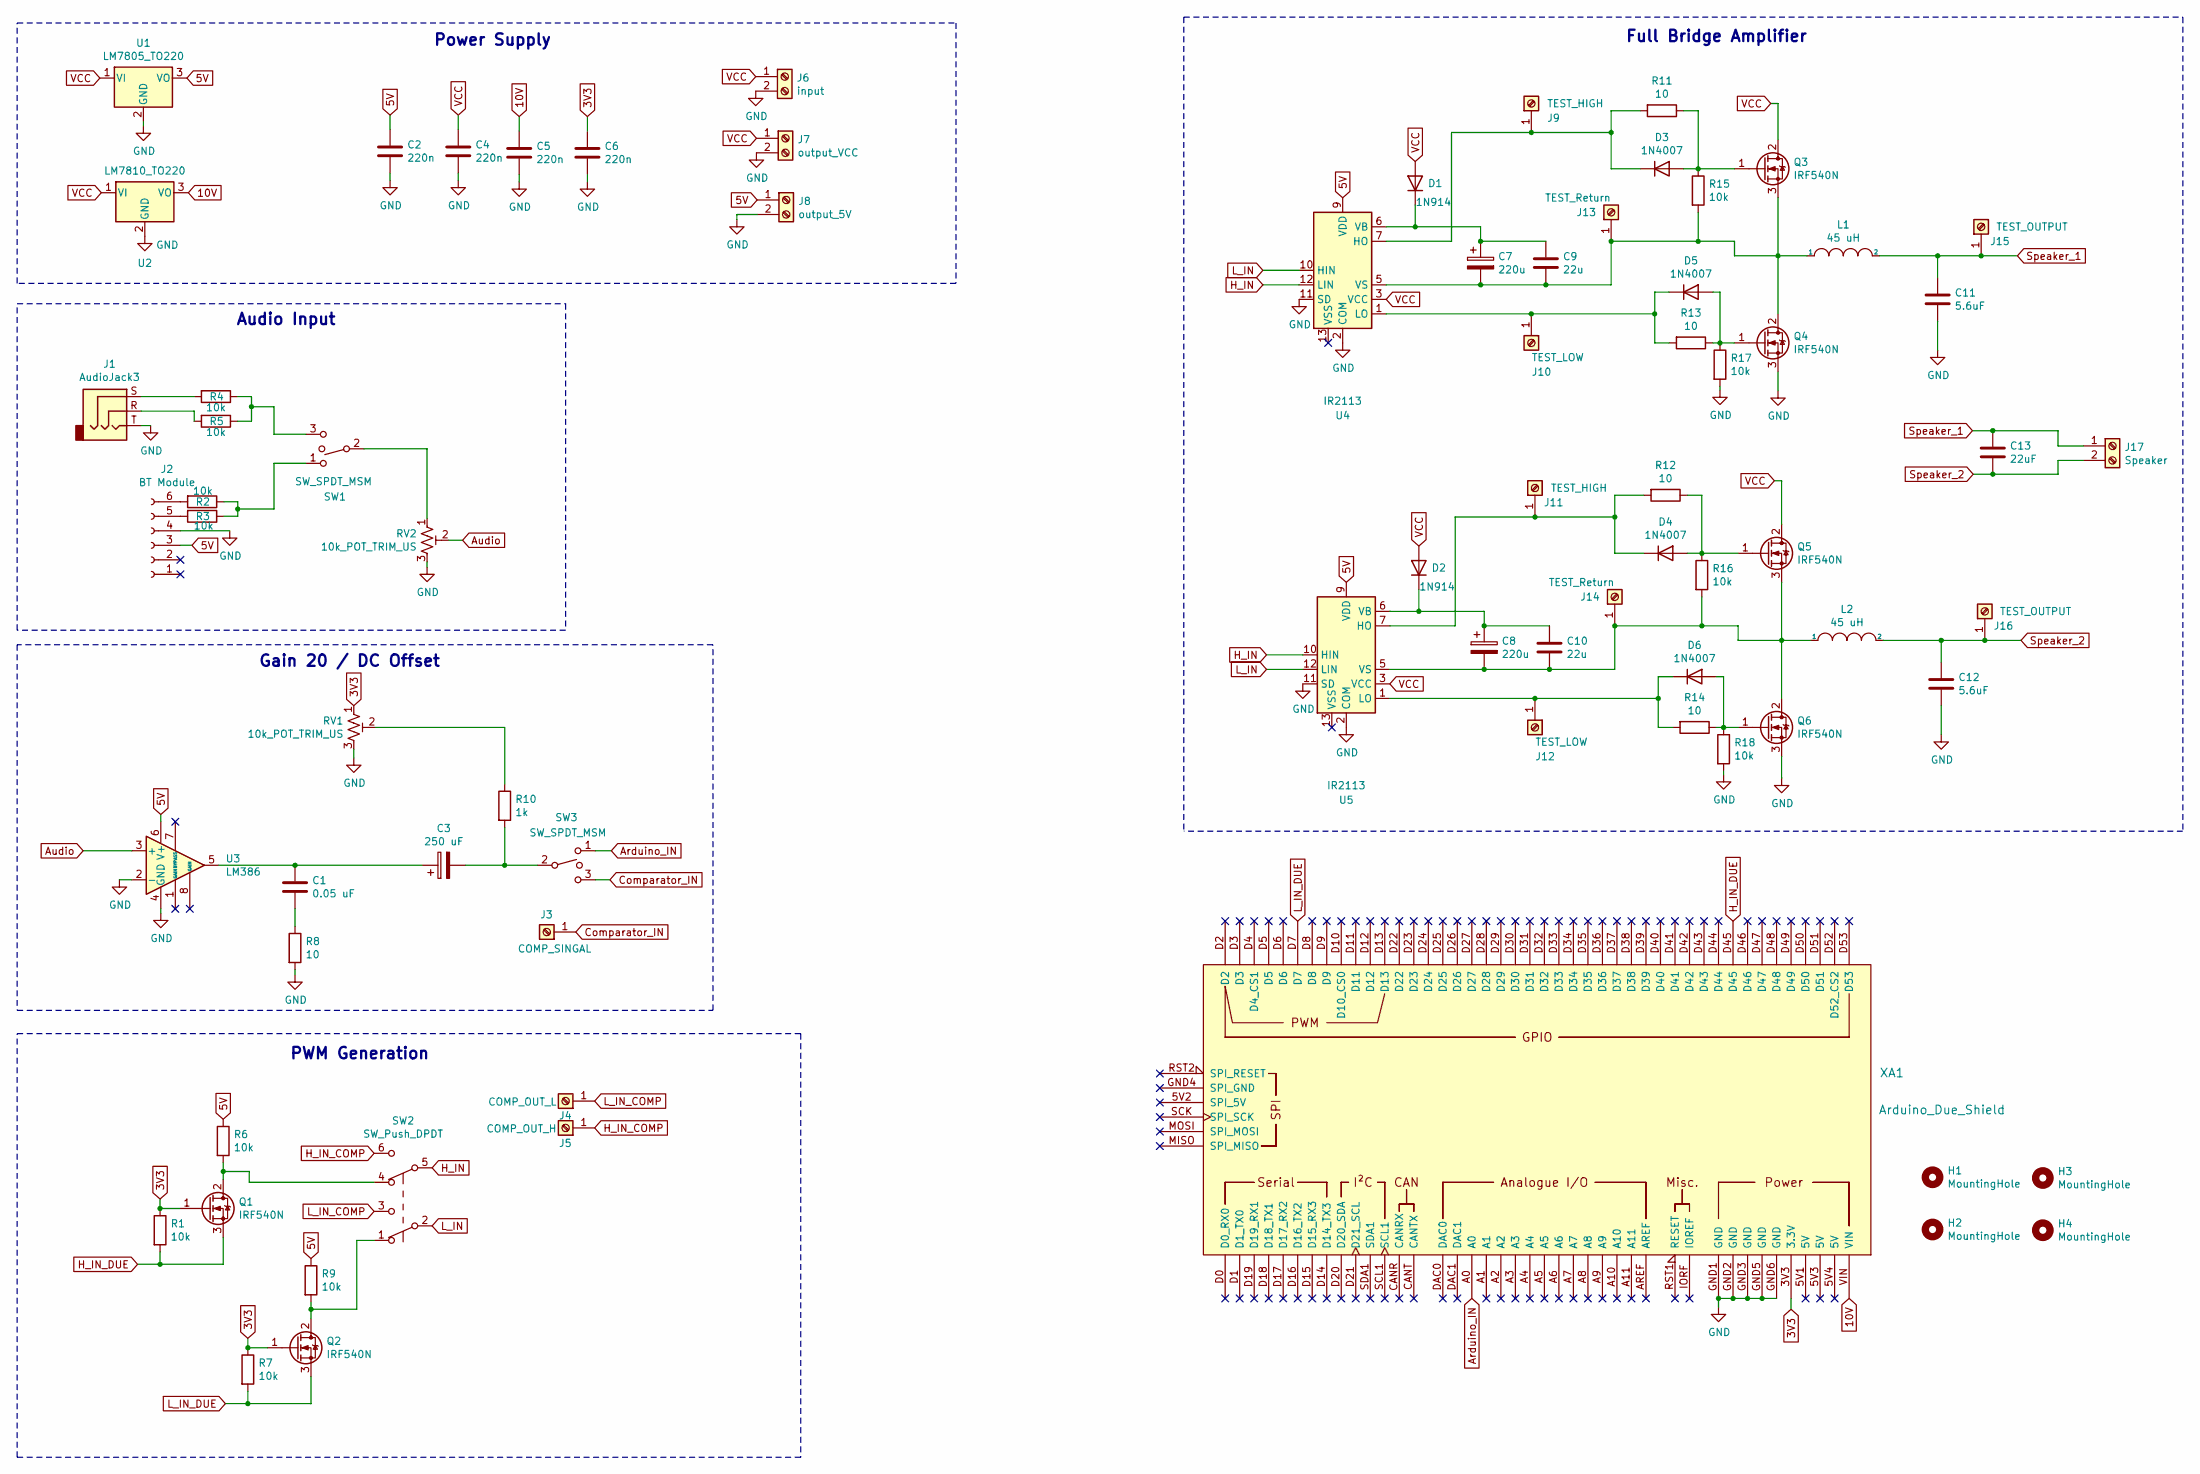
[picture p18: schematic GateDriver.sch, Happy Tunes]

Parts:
C1: 0.05 uF; C_Rect_L7.0mm_W2.5mm_P5.00mm
C2, C4, C5, C6: 220n; C_Rect_L7.0mm_W2.5mm_P5.00mm
C3: 250 uF; C_Rect_L7.0mm_W2.5mm_P5.00mm
C7, C8: 220u; C_Radial_D8.0mm_H7.0mm_P3.50mm
C9, C10: 22u; C_Rect_L7.0mm_W2.5mm_P5.00mm
C11, C12: 5.6uF; C_Rect_L7.0mm_W2.5mm_P5.00mm
C13: 22uF; C_Rect_L7.0mm_W2.5mm_P5.00mm
D1, D2: 1N914; D_DO-35_SOD27_P7.62mm_Horizontal
D3, D4, D5, D6: 1N4007; D_DO-41_SOD81_P10.16mm_Horizontal
H1, H2, H3, H4: MountingHole; MountingHole_2.2mm_M2
J1: AudioJack3; Jack_3.5mm_CUI_SJ1-3533NG_Horizontal
J2: BT Module; PinHeader_1x06_P2.54mm_Vertical
J3: COMP_SINGAL; Pin_D1.3mm_L11.0mm
J4: COMP_OUT_L; Pin_D1.3mm_L11.0mm
J5: COMP_OUT_H; Pin_D1.3mm_L11.0mm
J6: input; ScrewTerm
J7: output_VCC; ScrewTerm
J8: output_5V; ScrewTerm
J9, J11: TEST_HIGH; Pin_D1.3mm_L11.0mm
J10, J12: TEST_LOW; Pin_D1.3mm_L11.0mm
J13, J14: TEST_Return; Pin_D1.3mm_L11.0mm
J15, J16: TEST_OUTPUT; Pin_D1.3mm_L11.0mm
J17: Speaker; ScrewTerm
L1, L2: 45 uH; L_CommonMode_Toroid_Vertical_L24.0mm_W16.3mm_Px10.16mm_Py20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
Q1, Q2, Q3, Q4, Q5, Q6: IRF540N; TO-220-3_Vertical
R1, R2, R3, R4, R5, R6, R7, R9, R15, R16, R17, R18: 10k; R_Axial_DIN0204_L3.6mm_D1.6mm_P7.62mm_Horizontal
R8, R11, R12, R13, R14: 10; R_Axial_DIN0204_L3.6mm_D1.6mm_P7.62mm_Horizontal
R10: 1k; R_Axial_DIN0204_L3.6mm_D1.6mm_P7.62mm_Horizontal
RV1, RV2: 10k_POT_TRIM_US; Potentiometer_Alps_RK09K_Single_Horizontal
SW1, SW3: SW_SPDT_MSM; SW_CuK_OS102011MA1QN1_SPDT_Angled
SW2: SW_Push_DPDT; SW_CuK_JS202011AQN_DPDT_Angled
U1: LM7805_TO220; TO-220-3_Vertical
U2: LM7810_TO220; TO-220-3_Vertical
U3: LM386; DIP-8_W7.62mm_Socket
U4, U5: IR2113; DIP-14_W7.62mm_Socket
XA1: Arduino_Due_Shield

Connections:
3V3: C6.1, Q1.1 (G), Q2.1 (G), R1.1, R7.1, RV1.1, XA1.3V3 (3.3V)
5V: C2.1, J2.3, J8.1, R6.1, R9.1, U1.3 (VO), U3.6 (V+), U4.9 (VDD), U5.9 (VDD)
10V: C5.1, U2.3 (VO), XA1.VIN
Arduino_IN: SW3.1, XA1.A0
Audio: RV2.2, U3.3 (+)
Comparator_IN: J3.1, SW3.3
GND: C2.2, C4.2, C5.2, C6.2, C11.2, C12.2, J1.T, J2.4, J6.2, J7.2, J8.2, Q4.3 (S), Q6.3 (S), R8.2, R17.2, R18.2, RV1.3, RV2.3, U1.2 (GND), U2.2 (GND), U3.2 (-), U3.4 (GND), U4.2 (COM), U4.11 (SD), U5.2 (COM), U5.11 (SD), XA1.GND1 (GND), XA1.GND2 (GND), XA1.GND3 (GND), XA1.GND5 (GND), XA1.GND6 (GND)
H_IN: SW2.5 (B), U4.12 (LIN), U5.10 (HIN)
H_IN_COMP: J5.1, SW2.6 (C)
H_IN_DUE: Q1.3 (S), R1.2, XA1.D45
L_IN: SW2.2 (B), U4.10 (HIN), U5.12 (LIN)
L_IN_COMP: J4.1, SW2.3 (C)
L_IN_DUE: Q2.3 (S), R7.2, XA1.D7
unnamed: C1.1, C3.1, U3.5
unnamed: C1.2, R8.1
unnamed: C3.2, R10.2, SW3.2
unnamed: C7.1, C9.1, D1.1 (K), U4.6 (VB)
unnamed: C7.2, C9.2, J13.1, L1.1, Q3.3 (S), Q4.2 (D), R15.2, U4.5 (VS)
unnamed: C8.1, C10.1, D2.1 (K), U5.6 (VB)
unnamed: C8.2, C10.2, J14.1, L2.1, Q5.3 (S), Q6.2 (D), R16.2, U5.5 (VS)
unnamed: D3.1 (K), J9.1, R11.2, U4.7 (HO)
unnamed: D3.2 (A), Q3.1 (G), R11.1, R15.1
unnamed: D4.1 (K), J11.1, R12.2, U5.7 (HO)
unnamed: D4.2 (A), Q5.1 (G), R12.1, R16.1
unnamed: D5.1 (K), J10.1, R13.2, U4.1 (LO)
unnamed: D5.2 (A), Q4.1 (G), R13.1, R17.1
unnamed: D6.1 (K), J12.1, R14.2, U5.1 (LO)
unnamed: D6.2 (A), Q6.1 (G), R14.1, R18.1
unnamed: J1.R, R5.2
unnamed: J1.S, R4.2
unnamed: J2.5, R3.2
unnamed: J2.6, R2.2
unnamed: Q1.2 (D), R6.2, SW2.4 (A)
unnamed: Q2.2 (D), R9.2, SW2.1 (A)
unnamed: R2.1, R3.1, SW1.1
unnamed: R4.1, R5.1, SW1.3
unnamed: R10.1, RV1.2
unnamed: RV2.1, SW1.2
Speaker_1: C11.1, C13.1, J15.1, J17.1, L1.2
Speaker_2: C12.1, C13.2, J16.1, J17.2, L2.2
VCC: C4.1, D1.2 (A), D2.2 (A), J6.1, J7.1, Q3.2 (D), Q5.2 (D), U1.1 (VI), U2.1 (VI), U4.3 (VCC), U5.3 (VCC)

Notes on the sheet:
Audio Input
Gain 20 / DC Offset
Full Bridge Amplifier
Power Supply
PWM Generation

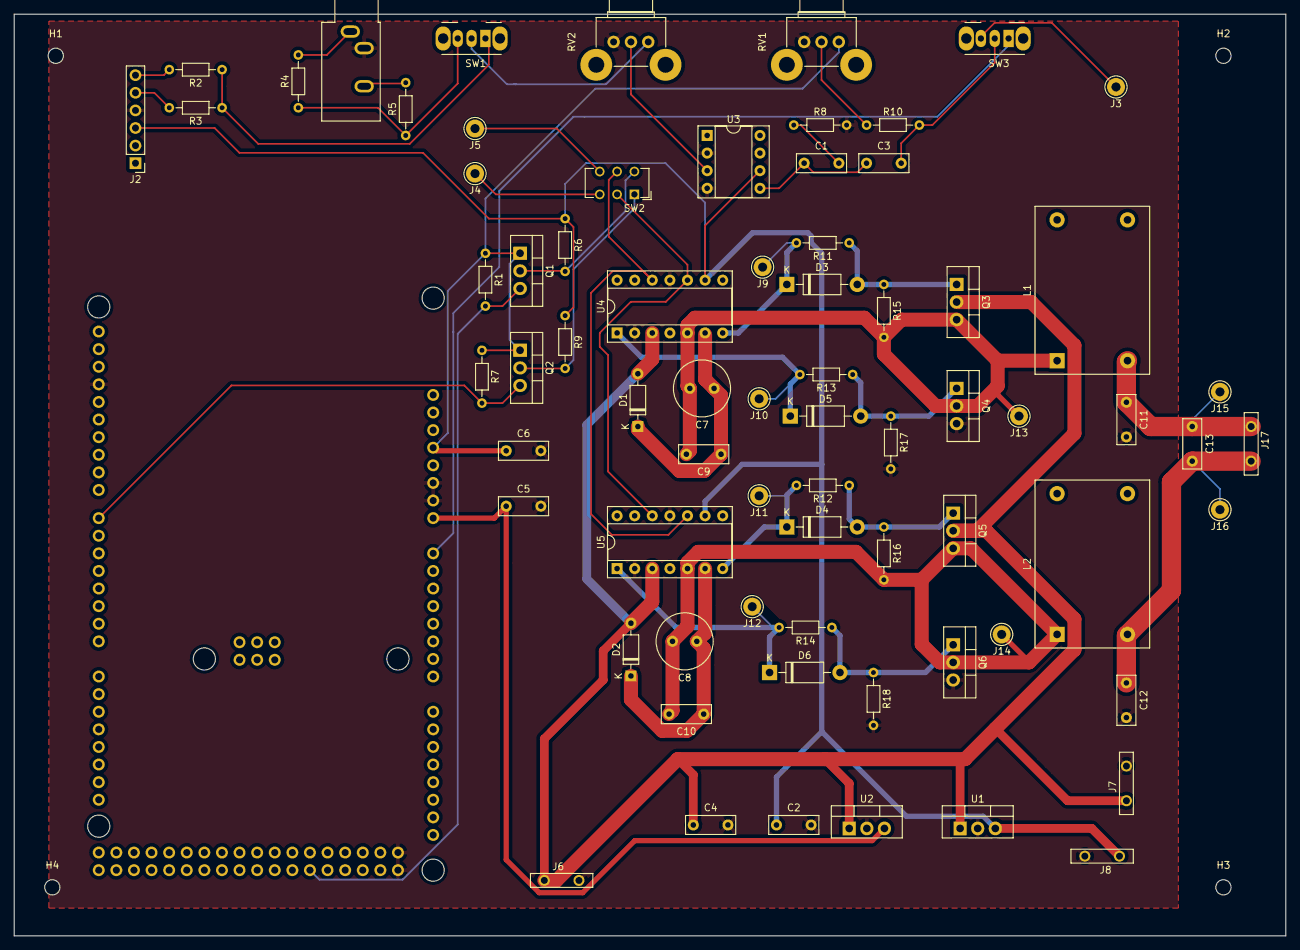
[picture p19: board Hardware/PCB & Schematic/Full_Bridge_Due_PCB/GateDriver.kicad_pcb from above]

Board: 2 copper layers, 183.5 x 133.0 mm, 77 parts (1 on the bottom side), 41 nets.

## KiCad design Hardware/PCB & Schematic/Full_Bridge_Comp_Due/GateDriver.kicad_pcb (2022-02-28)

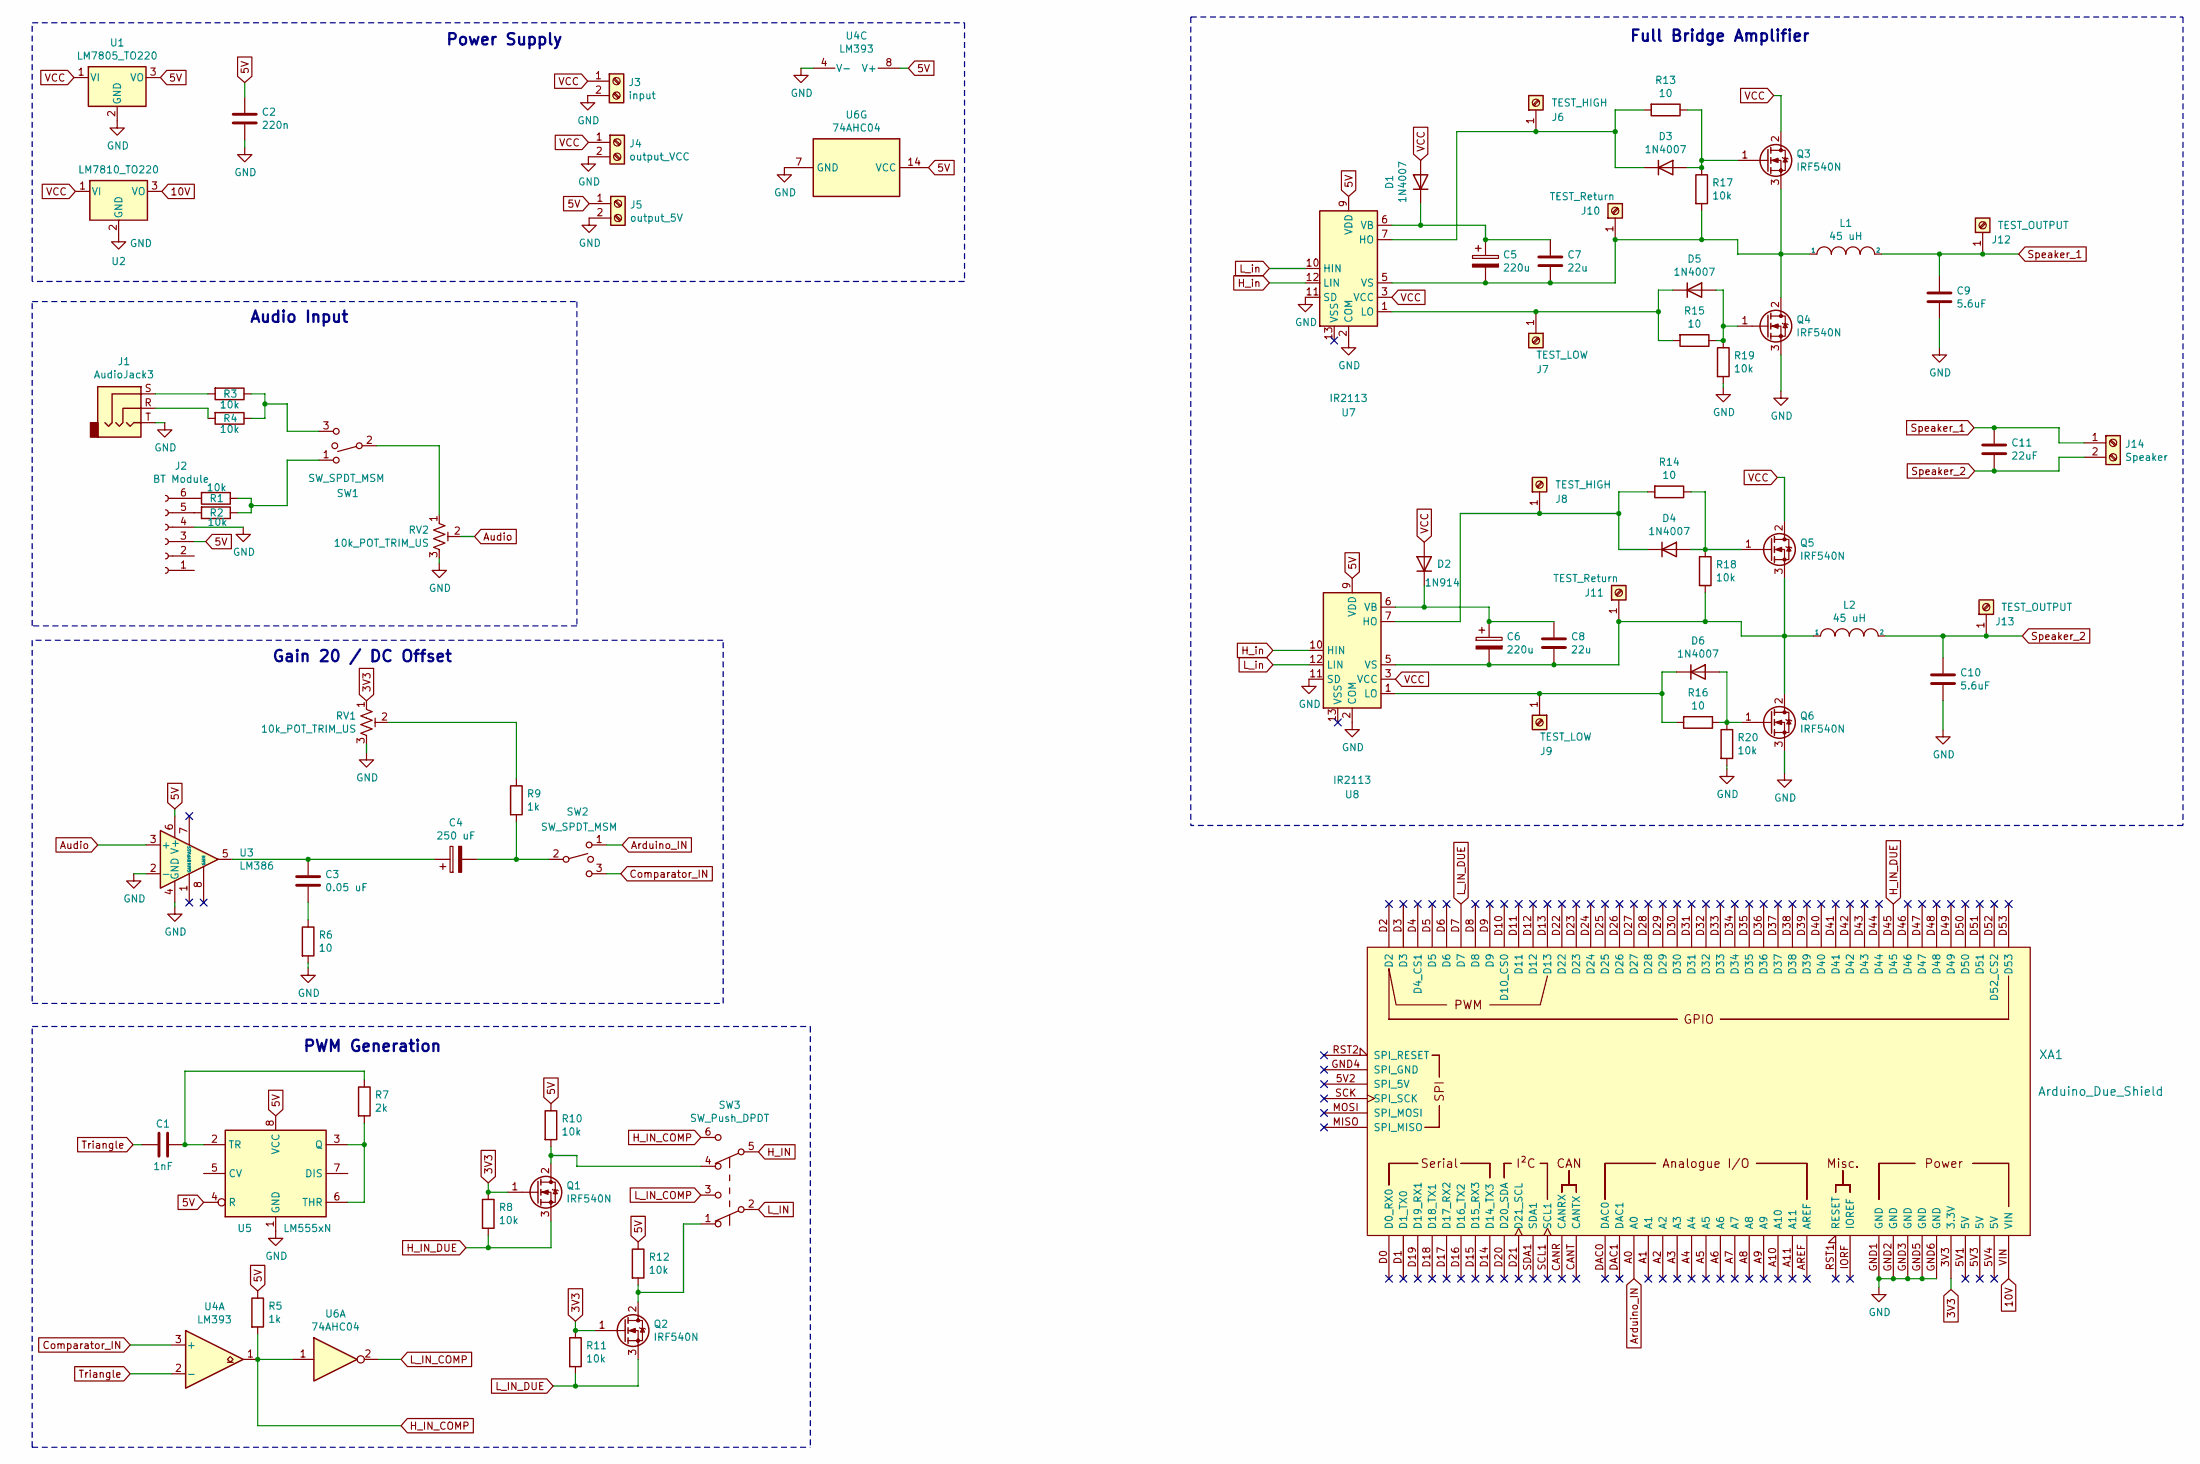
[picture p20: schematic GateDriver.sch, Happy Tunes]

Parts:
C1: 1nF; C_Rect_L7.0mm_W2.5mm_P5.00mm
C2: 220n; C_Rect_L7.0mm_W2.5mm_P5.00mm
C3: 0.05 uF; C_Rect_L7.0mm_W2.5mm_P5.00mm
C4: 250 uF; C_Rect_L7.0mm_W2.5mm_P5.00mm
C5, C6: 220u; C_Radial_D8.0mm_H7.0mm_P3.50mm
C7, C8: 22u; C_Rect_L7.0mm_W2.5mm_P5.00mm
C9, C10: 5.6uF; C_Rect_L7.0mm_W2.5mm_P5.00mm
C11: 22uF; C_Rect_L7.0mm_W2.5mm_P5.00mm
D1, D3, D4, D5, D6: 1N4007; D_DO-41_SOD81_P10.16mm_Horizontal
D2: 1N914; D_DO-35_SOD27_P7.62mm_Horizontal
J1: AudioJack3; Jack_3.5mm_CUI_SJ1-3533NG_Horizontal
J2: BT Module; PinHeader_1x06_P1.00mm_Vertical
J3: input; ScrewTerm
J4: output_VCC; ScrewTerm
J5: output_5V; ScrewTerm
J6, J8: TEST_HIGH; Pin_D1.3mm_L11.0mm
J7, J9: TEST_LOW; Pin_D1.3mm_L11.0mm
J10, J11: TEST_Return; Pin_D1.3mm_L11.0mm
J12, J13: TEST_OUTPUT; Pin_D1.3mm_L11.0mm
J14: Speaker; ScrewTerm
L1, L2: 45 uH; L_CommonMode_Toroid_Vertical_L24.0mm_W16.3mm_Px10.16mm_Py20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
Q1, Q2, Q3, Q4, Q5, Q6: IRF540N; TO-220-3_Vertical
R1, R2, R3, R4, R8, R10, R11, R12, R17, R18, R19, R20: 10k; R_Axial_DIN0204_L3.6mm_D1.6mm_P7.62mm_Horizontal
R5, R9: 1k; R_Axial_DIN0204_L3.6mm_D1.6mm_P7.62mm_Horizontal
R6, R13, R14, R15, R16: 10; R_Axial_DIN0204_L3.6mm_D1.6mm_P7.62mm_Horizontal
R7: 2k; R_Axial_DIN0204_L3.6mm_D1.6mm_P7.62mm_Horizontal
RV1, RV2: 10k_POT_TRIM_US; Potentiometer_Alps_RK09K_Single_Horizontal
SW1, SW2: SW_SPDT_MSM; SW_CuK_OS102011MA1QN1_SPDT_Angled
SW3: SW_Push_DPDT; SW_CuK_JS202011AQN_DPDT_Angled
U1: LM7805_TO220; TO-220-3_Vertical
U2: LM7810_TO220; TO-220-3_Vertical
U3: LM386; PowerIntegrations_PDIP-8B
U4: LM393; PowerIntegrations_PDIP-8B
U5: LM555xN; DIP-8_W7.62mm
U6: 74AHC04; DIP-14_W7.62mm
U7, U8: IR2113; DIP-14_W7.62mm
XA1: Arduino_Due_Shield

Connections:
3V3: Q1.1 (G), Q2.1 (G), R8.1, R11.1, RV1.1, XA1.3V3 (3.3V)
5V: C2.1, J2.3, J5.1, R5.1, R10.1, R12.1, U1.3 (VO), U3.6 (V+), U4.8 (V+), U5.4 (R), U5.8 (VCC), U6.14 (VCC), U7.9 (VDD), U8.9 (VDD)
10V: U2.3 (VO), XA1.VIN
Arduino_IN: SW2.1, XA1.A0
Audio: RV2.2, U3.3 (+)
Comparator_IN: SW2.3
GND: C2.2, C9.2, C10.2, J1.T, J2.4, J3.2, J4.2, J5.2, Q4.3 (S), Q6.3 (S), R6.2, R19.2, R20.2, RV1.3, RV2.3, U1.2 (GND), U2.2 (GND), U3.2 (-), U3.4 (GND), U4.4 (V-), U5.1 (GND), U6.7 (GND), U7.2 (COM), U7.11 (SD), U8.2 (COM), U8.11 (SD), XA1.GND1 (GND), XA1.GND2 (GND), XA1.GND3 (GND), XA1.GND5 (GND), XA1.GND6 (GND)
H_IN: SW3.5 (B)
H_IN_COMP: R5.2, SW3.6 (C), U4.1, U6.1
H_IN_DUE: Q1.3 (S), R8.2, XA1.D45
H_in: U7.12 (LIN), U8.10 (HIN)
L_IN: SW3.2 (B)
L_IN_COMP: SW3.3 (C), U6.2
L_IN_DUE: Q2.3 (S), R11.2, XA1.D7
L_in: U7.10 (HIN), U8.12 (LIN)
unnamed: C1.2, R7.1, U5.2 (TR)
unnamed: C3.1, C4.1, U3.5
unnamed: C3.2, R6.1
unnamed: C4.2, R9.2, SW2.2
unnamed: C5.1, C7.1, D1.1 (K), U7.6 (VB)
unnamed: C5.2, C7.2, J10.1, L1.1, Q3.3 (S), Q4.2 (D), R17.2, U7.5 (VS)
unnamed: C6.1, C8.1, D2.1 (K), U8.6 (VB)
unnamed: C6.2, C8.2, J11.1, L2.1, Q5.3 (S), Q6.2 (D), R18.2, U8.5 (VS)
unnamed: D3.1 (K), J6.1, R13.2, U7.7 (HO)
unnamed: D3.2 (A), Q3.1 (G), R13.1, R17.1
unnamed: D4.1 (K), J8.1, R14.2, U8.7 (HO)
unnamed: D4.2 (A), Q5.1 (G), R14.1, R18.1
unnamed: D5.1 (K), J7.1, R15.2, U7.1 (LO)
unnamed: D5.2 (A), Q4.1 (G), R15.1, R19.1
unnamed: D6.1 (K), J9.1, R16.2, U8.1 (LO)
unnamed: D6.2 (A), Q6.1 (G), R16.1, R20.1
unnamed: J1.R, R4.2
unnamed: J1.S, R3.2
unnamed: J2.5, R2.2
unnamed: J2.6, R1.2
unnamed: Q1.2 (D), R10.2, SW3.4 (A)
unnamed: Q2.2 (D), R12.2, SW3.1 (A)
unnamed: R1.1, R2.1, SW1.1
unnamed: R3.1, R4.1, SW1.3
unnamed: R7.2, U5.3 (Q), U5.6 (THR)
unnamed: R9.1, RV1.2
unnamed: RV2.1, SW1.2
Speaker_1: C9.1, C11.1, J12.1, J14.1, L1.2
Speaker_2: C10.1, C11.2, J13.1, J14.2, L2.2
Triangle: C1.1, U4.2 (-)
VCC: D1.2 (A), D2.2 (A), J3.1, J4.1, Q3.2 (D), Q5.2 (D), U1.1 (VI), U2.1 (VI), U7.3 (VCC), U8.3 (VCC)

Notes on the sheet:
Audio Input
Gain 20 / DC Offset
Full Bridge Amplifier
Power Supply
PWM Generation

Board: 2 copper layers, 73 parts (0 on the bottom side), 43 nets, no tracks yet.

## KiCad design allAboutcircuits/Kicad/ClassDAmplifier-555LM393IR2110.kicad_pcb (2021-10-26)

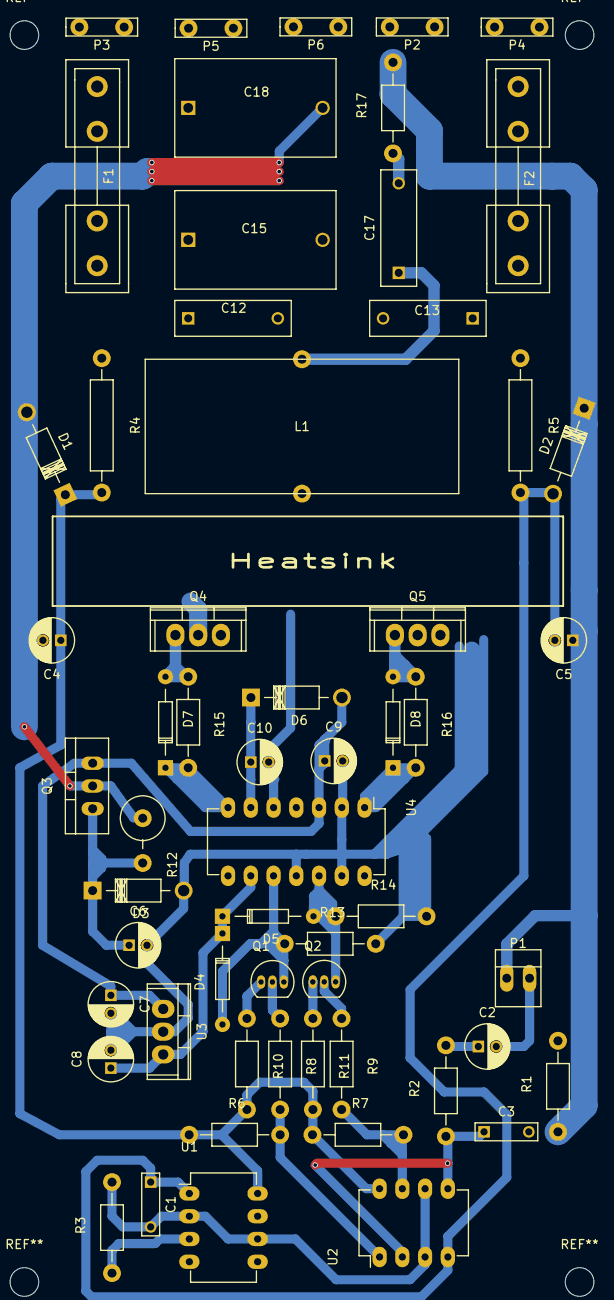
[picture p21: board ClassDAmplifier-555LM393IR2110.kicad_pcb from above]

Board: 2 copper layers, 59 parts (1 on the bottom side), 31 nets.

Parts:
C1: 2n2; C_Rect_L7_W2_P5
C2: 10uF; C_Radial_D5_L11_P2
C3: 1n; C_Rect_L7_W2_P5
C4, C5, C6, C7, C8, C9: 47uF; C_Radial_D5_L11_P2
C10: 22uF; C_Radial_D5_L11_P2
C11: 100n; C_0805_HandSoldering
C12, C13, C17: 220n; C_Rect_L13_W4_P10
C15, C18: 470nF; C_Rect_L18_W11_H19_P15
D1, D2: 5V1; Diode_DO-41_SOD81_Horizontal_RM10
D3: 12V; Diode_DO-41_SOD81_Horizontal_RM10
D4, D5, D7, D8: 1N4148; Diode_DO-35_SOD27_Horizontal_RM10
D6: MUR120; Diode_DO-41_SOD81_Horizontal_RM10
F1, F2: 6A; Fuseholder5x20_horiz_open_inline_Type-I
L1: 22uH; Inductor_T106-2
P1: Input; PINHEAD1-2
P2, P6: GND; Blade_Conn
P3: +30; Blade_Conn
P4: -30; Blade_Conn
P5: OUT; Blade_Conn
Q1, Q2: 2N5401; TO-92_Inline_Narrow_Oval
Q3: BC241C; TO-220_Neutral123_Vertical
Q4, Q5: IRF540N; TO-220
R1: 330k; Resistor_Horizontal_RM10mm
R2: 2k2; Resistor_Horizontal_RM10mm
R3: 3.3k; Resistor_Horizontal_RM10mm
R4, R5: 1K2W; Resistor_Horizontal_RM15mm
R6, R7, R8, R9: 1k; Resistor_Horizontal_RM10mm
R10, R11: 10k; Resistor_Horizontal_RM10mm
R12: 10k; Resistor_Vertical_RM5mm
R13, R14: 6.8k; Resistor_Horizontal_RM10mm
R15, R16, R17: 10; Resistor_Horizontal_RM10mm
U1: LM555CN; DIP-8_W7.62mm_LongPads
U2: LM393; DIP-8_W7.62mm_LongPads
U3: LM7805CT; TO-220
U4: IR2110; DIP-14_W7.62mm_LongPads

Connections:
+5V: C4.1, D1.1, R4.2, R6.1, R7.1, R10.2, R11.2, U1.8, U2.8
+5V_2: C8.1, D4.1, D5.1, U3.3, U4.9
+12V: C7.1, C9.1, D6.2, Q3.3, U3.1, U4.3
+30V: C12.1, F1.2, Q4.2, R4.1
-5V: C1.1, C5.2, D2.2, R5.2, U1.1, U2.4
-30V: C6.2, C7.2, C8.2, C9.2, C13.1, D3.2, F2.2, Q5.3, R5.1, R13.2, R14.2, U3.2, U4.2, U4.11, U4.13
GND: C3.2, C4.2, C5.1, C12.2, C13.2, C15.2, C18.2, D1.2, D2.1, P1.1, P2.1, P6.1, Q3.2, R1.1, R12.1, R17.2
unnamed: C2.1, R2.2
unnamed: C2.2, P1.2, R1.2
unnamed: C3.1, R2.1, U2.2, U2.5
unnamed: C6.1, D3.1, Q3.1, R12.2
unnamed: C10.1, C11.1, D6.1, U4.6
unnamed: C10.2, C11.2, L1.1, Q4.3, Q5.2, U4.5
unnamed: C15.1, C17.1, C18.1, L1.2, P5.1
unnamed: C17.2, R17.1
unnamed: D4.2, Q1.3, R13.1, U4.10
unnamed: D5.2, Q2.3, R14.1, U4.12
unnamed: D7.1, R15.2, U4.7
unnamed: D7.2, Q4.1, R15.1
unnamed: D8.1, R16.2, U4.1
unnamed: D8.2, Q5.1, R16.1
unnamed: F1.1, P3.1
unnamed: F2.1, P4.1
unnamed: Q1.1, R10.1
unnamed: Q1.2, R8.1
unnamed: Q2.1, R11.1
unnamed: Q2.2, R9.1
unnamed: R3.1, U1.3
unnamed: R6.2, R8.2, U2.1
unnamed: R7.2, R9.2, U2.7
triangle: C1.2, R3.2, U1.2, U1.6, U2.3, U2.6

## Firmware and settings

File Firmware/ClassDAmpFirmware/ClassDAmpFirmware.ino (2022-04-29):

/*
Class D Amp Firmware

PWM high is on pin 45, PWM low is on pin 7.
Analog in (audio) is on pin A0
Be aware the Due runs at 3.3V.
*/

#include <Arduino.h>

#define DEFAULT_DEADTIME 10 // I think this should be the 14 for our gate driver. Adjust to determine
#define DEFAULT_PERIOD 952   // 84E6/952/2 = 44,117.64khz
#define DEFAULT_DUTY DEFAULT_PERIOD/3     

#define MAX_AMP 952
#define MAX_DEADTIME 10 // Arbitrary, should be lower like probably in the 10's
#define MAX_SAMPLE_FREQ 44100
#define MAX_ADC 4095
#define SAMPLES_QUIET 100
#define FILTER_SAMPLES 4
#define FILTER_INPUT_OUTPUT_ENABLE
#define FILTER_INPUT_OUTPUT_SAMPLES 1000

uint32_t channel;
bool dacEnable = true;

#ifdef FILTER_INPUT_OUTPUT_ENABLE
uint16_t samples[2][1000];
uint16_t sampleIndex = 0;
bool sampleEn = false;
#endif

uint32_t logApprox(uint32_t input, uint32_t order){
    uint32_t output = input;
    for(uint32_t i = 0; i < order; i++){
        output *= input;
        output >>= 12;
    }    
    return output;
}
/*
int16_t filter(int32_t signal){
    #define POLES 3
    //static double y[3] = {0};
    static uint16_t x[3] = {0};
    
    // Shift old inputs so that the index is their n-m where n is the current
    // sample and m is the m'th after the current one.
    //memmove(x+1, x, POLES*sizeof(x[0]));
    //x[0] = signal;

    // Shift old outputs, same as above.
    //memmove(y+1, y, (POLES-1)*sizeof(y[0]));
    //y[0] = 0;

    // LPF at 20khz.
    // Found using MatLab, [b,a] = butter(2,fc/(fs/2)) where fc = 20k, fs=44117
    //const double a[3] = {0, -1.9497, 0.9509};
    //const double b[3] = {0.00030912, 0.00061824, 0.00030912};

    // Calculate the filtered output and save result for next sample
    //y[0] = b[0]*x[0]+b[1]*x[1]+b[2]*x[2]-a[1]*y[1]-a[2]*y[2];
    
    // Direct-Form II at 10kHz
    /*
    const double a[3] = {1, -0.171886271172, 0.176800554};
    const double b[3] = {1, 2, 1};
    x[0] = signal - a[1]*x[1] - a[2]*x[2];
    y[0] = b[0] * x[0] + b[1] * x[1] + b[2]*x[2];
    */
    /*
    for(uint8_t i = 0; i < POLES; i++){
        y[0] += b[i]*x[i]-a[i]*y[i];
    }
    

    // Return most recent result.
    return x[0];
}
*/

uint16_t filter(uint16_t input){
    static int32_t v[3] = {0};
    v[0] = v[1];
    v[1] = v[2];
    v[2] = ((((input * 263432L) >>  2) + ((v[0] * -370778L) >> 3) + ((v[1] * 360472L) >> 3)	)+131072) >> 18; 
    return (short)(((v[0] + v[2])+2 * v[1]));
}

// Sets up the ADC on the A0 pin.
void setupADC(){
    ADC->ADC_WPMR &= ~(ADC_WPMR_WPEN); // Disable Write Protect Mode
    ADC->ADC_CHER |= ADC_CHER_CH7; // Enable A0 pin
    //ADC->ADC_CHER |= ADC_CHER_CH6;// g_APinDescription[1].ulADCChannelNumber; // Enable A1 pin
    //ADC->ADC_CHER |= ADC_CHER_CH5;
    ADC->ADC_MR = 0; 
    ADC->ADC_MR = ADC_MR_PRESCAL(4);    //ADC Clock set to 8MHz 
    ADC->ADC_MR |= ADC_MR_TRACKTIM(3); 
    ADC->ADC_MR |= ADC_MR_STARTUP_SUT8; 
    ADC->ADC_EMR = 0; // TODO: Figure out this register
    return;
}

void setupDAC () {
  PIOB->PIO_PDR |= PIO_PDR_P15 | PIO_PDR_P16;  // Disable GPIO on corresponding pins DAC0 and DAC1
  PMC->PMC_PCER1 |= PMC_PCER1_PID38 ;     // DACC power ON
  DACC->DACC_CR = DACC_CR_SWRST ;         // reset DACC

  DACC->DACC_MR = DACC_MR_REFRESH (1)
                  | DACC_MR_STARTUP_0
                  | DACC_MR_MAXS
                  | DACC_MR_USER_SEL_CHANNEL1;

  DACC->DACC_CHER =  DACC_CHER_CH1;      // enable DAC  channel 1
}

// Sets up PWM at 44117 Hz, Differential Inputs, and Deadtime
void setupPWM(){
    uint32_t ulPin = 7;

    // PWM Startup code

    // Starts the PWM clocks. Required to enable PWM.
    pmc_enable_periph_clk(PWM_INTERFACE_ID);
    // We'll be using the main clock without any dividers. This allows us the highest resolution.
 
    // Some Arduino library code to help with determining the channel
    channel = g_APinDescription[ulPin].ulPWMChannel;
    
    // Setup PWM for this pin and complementary pin
    PIO_Configure(g_APinDescription[ulPin].pPort,
            g_APinDescription[ulPin].ulPinType,
            g_APinDescription[ulPin].ulPin | PIO_PC18,      // In addition to the pin enabled from this function,
            g_APinDescription[ulPin].ulPinConfiguration);   // also enable the complementary pin.
  
    // Configure the channel
    PWM->PWM_CH_NUM[0].PWM_CMR = 1;
    // Disable ul_channel (effective at the end of the current period)
    if ((PWM->PWM_SR & (1 << channel)) != 0) {
        PWM->PWM_DIS = 1 << channel;
        while ((PWM->PWM_SR & (1 << channel)) != 0);
    }
    // Configure ul_channel   
    PWM->PWM_CH_NUM[channel].PWM_CMR = PWM_CMR_DTE | PWM_CMR_CALG; // Enable Deadtime and center align

    // Deadtime value set
    PWM->PWM_CH_NUM[channel].PWM_DT = DEFAULT_DEADTIME << PWM_DT_DTL_Pos | DEFAULT_DEADTIME;
    // Period value set
    PWMC_SetPeriod(PWM, channel, DEFAULT_PERIOD);
    PWMC_SetDutyCycle(PWM_INTERFACE, channel, DEFAULT_DUTY);
    PWMC_EnableChannel(PWM_INTERFACE, channel);

    PWMC_EnableChannelIt(PWM, channel);
    NVIC_EnableIRQ(PWM_IRQn);

    g_pinStatus[ulPin] = (g_pinStatus[ulPin] & 0xF0) | PIN_STATUS_PWM;
    return;
}

void setupTimer(){
    return;   
}    

// Sets the deadtime in the update register
//
// Inputs: dtTime, The number of cycles there exists deadtime.
//
// Currently set up so that the deadtime between the HI to LO and LO to HI waveforms are the same.
// This can be changed if needed.
void setDT(uint16_t dtTime){
    PWM->PWM_CH_NUM[channel].PWM_DTUPD = dtTime << 16 | dtTime;
    return;
}

// Sets the duty cycle of the PWM
// 
// Inputs: duty, The number of cycles the HI side of the input is enabled.
//               Note: The LO side is complementary
void setDuty(uint16_t duty){
    PWMC_SetDutyCycle(PWM, channel, duty);
    return;
}

int16_t mapRange(uint16_t input, uint16_t inLow, uint16_t inHigh, uint16_t outLow, uint16_t outHigh){
    return outLow+(input-inLow)*(double)(outHigh-outLow)/(double)(inHigh-inLow);
}

int16_t rollingAverage(int16_t input){
    static uint16_t values[FILTER_SAMPLES] = {0};
    static uint32_t index = 0;
    if(index == FILTER_SAMPLES) index = 0;
    static int32_t sum = 0;
    sum -= values[index];
    sum += input;
    values[index++] = input;
    return sum/FILTER_SAMPLES;
}

int16_t rollingAverageQuiet(int16_t input){
    static uint16_t values[SAMPLES_QUIET] = {0};
    static uint32_t index = 0;
    if(index == SAMPLES_QUIET) index = 0;
    static int32_t sum = 0;
    sum -= values[index];
    sum += input;
    values[index++] = input;
    return sum/SAMPLES_QUIET;
}

// PWM Interrupt Handler
// Every time the PWM completes a cycle it triggers an interrupt.
// This reads the value in the ADC, starts a new ADC reading, and sets the PWM duty to the maped value from the ADC.
void PWM_Handler() {
    PWM->PWM_ISR1;                          // Clear flag by reading register
    uint32_t Adc0Result = ADC->ADC_CDR[7];            // Read the previous result
    uint32_t Adc1Result = ADC->ADC_CDR[6];
    ADC->ADC_CR |= ADC_CR_START;            // Begin the next ADC conversion. 
    //int16_t filteredReading = Adc0Result;
    //int16_t filteredReading = rollingAverage(Adc0Result);
    int16_t filteredReading = filter(Adc0Result);
    /*
    if(Adc0Result >= filteredReading - 10 && Adc0Result <= filteredReading + 10){
        filteredReading = 2047;
    }
    */
/*
#ifdef FILTER_INPUT_OUTPUT_ENABLE
    if(sampleEn == true){
        samples[0][sampleIndex] = Adc0Result;
        samples[1][sampleIndex++] = filteredReading;
    }
#endif
*/
    //int16_t filteredReading = filter(AdcResult-2048.0);
    //uint16_t filteredReading = logApprox(AdcResult,5);
    if(filteredReading > 4095) filteredReading = 4095;
    if(filteredReading < 0) filteredReading = 0;
    uint16_t mappedResult = mapRange(filteredReading, 0, MAX_ADC, 0, MAX_AMP);
    //int16_t mappedResult = mapRange(filteredReading, 1302, 2730, 0, MAX_AMP);
    if(mappedResult > 952) mappedResult = 952;
    if(mappedResult < 0) mappedResult = 0;
    PWMC_SetDutyCycle(PWM, channel, (uint16_t)mappedResult);
    //PWMC_SetDutyCycle(PWM, channel, 100);
    if(dacEnable == true){
        DACC->DACC_CDR = (uint32_t) filteredReading;
    }
    
    return;
}

// Sine wave generator
/*
void PWM_Handler() {
    PWM->PWM_ISR1;                          // Clear flag by reading register
    static uint32_t timeStep = 0;
    if(timeStep++ == 44116) timeStep = 0;
#define FREQUENCY 4300
    int16_t filteredReading = 1500*sin(2*FREQUENCY*(double)timeStep/44117.0)+2048;
    if(filteredReading > 4095) filteredReading = 4095;
    if(filteredReading < 0) filteredReading = 0;
    uint16_t mappedResult = map(filteredReading, 0, MAX_ADC, 0, MAX_AMP);
    PWMC_SetDutyCycle(PWM, channel, mappedResult);
    DACC->DACC_CDR = (uint32_t) filteredReading;
    return;
}
*/
void setup() {
  setupADC();
  setupPWM();
  setupTimer();
  if(dacEnable == true) setupDAC();
  Serial.begin(9600);
  delay(5000);
  Serial.println("boo");
  sampleEn = true;
}

void loop() {
#ifdef FILTER_INPUT_OUTPUT_ENABLE
/*
    if(sampleIndex == 1000){
        sampleEn = false;
        sampleIndex = 0;
        for(int i = 0; i < 1000; i++){
           Serial.print(i);
           Serial.print(",");
           Serial.print(samples[0][i]);
           Serial.print(",");
           Serial.println(samples[1][i]);
        }
    }
*/
#endif
}

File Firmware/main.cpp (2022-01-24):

/*
PWM Tester for Gate Driver

PWM high is on pin 45, PWM low is on pin 7.
Analog in (audio) is on pin A0
Be aware the Due runs at 3.3V.


Serial interface instructions
To change the amplitude, send it "a ##" whatever value between 0 and 952, less the deadtime. 
    The setting below ADC, controls whether it listens to the ADC or serial interface
Deadtime is changed using "d ##" with some value between 0 and 100. I think it "should be" 
    around 14 based on what timing we need I remember from the datasheet. You can set both 
    at the same time using "d ## a ##" or "a ## d ##". 
*/

#include <Arduino.h>

#define DEFAULTDEADTIME 14 // I think this should be the 14 for our gate driver. Adjust to determine
#define DEFAULTPERIOD 952   // 84E6/952/2 = 44,117.64khz
#define DEFAULTDUTY DEFAULTPERIOD/3     

#define MAXAMP 952
#define MAXDEADTIME 100 // Arbitrary, should be lower like probably in the 
#define MAXSAMPLEFREQ 44100
#define MAXWAVEFREQ 20000
#define MAXADC 4095
#define DEFAULTWAVE flat

enum waveTypes {flat, square, triangle, sine} waveType;
char waveTypeNames[][10] = {"flat\0", "square\0", "triangle\0", "sine\0"};

char string[100];
uint16_t amplitude, deadtime, sampleFreq, waveFreq;
uint32_t AdcResult = 0;
uint32_t channel;
bool adcEnable = false;

bool parseSerial(char *string, uint16_t *amplitude, uint16_t *deadtime, uint16_t *sampleFreq, enum waveTypes *waveType, uint16_t *waveFreq){
    uint8_t currentChar = 0;
    uint8_t action;
    long long int tempValue;
    while(*string != 0){
        action = *string++;
        do{currentChar = *string++;} while(currentChar != ' ');
        tempValue = atoll(string);
        switch(action){
            case 'A':
            case 'a':
                *amplitude = tempValue <= MAXAMP ? tempValue : MAXAMP; break;
            case 'D':
            case 'd':
                *deadtime = tempValue <= MAXDEADTIME ? tempValue : MAXDEADTIME; break;
            case 'F':
            case 'f':
                *waveFreq = tempValue <= MAXWAVEFREQ ? tempValue : MAXWAVEFREQ; break;
            case 'S':
            case 's':
                *sampleFreq = tempValue <= MAXSAMPLEFREQ ? tempValue : MAXSAMPLEFREQ; break;
            case 'T':
            case 't':
                *waveType = tempValue < sizeof(enum waveTypes) ? (enum waveTypes)tempValue : DEFAULTWAVE;
                break;
            default:
                return false;
        }
    }
    return true;
}

void setupADC(){
    ADC->ADC_WPMR &= ~(ADC_WPMR_WPEN); // Disable Write Protect Mode
    ADC->ADC_CHER |= ADC_CHER_CH7; // Enable A0 pin
    ADC->ADC_MR = 0; 
    ADC->ADC_MR = ADC_MR_PRESCAL(4);    //ADC Clock set to 8MHz 
    ADC->ADC_MR |= ADC_MR_TRACKTIM(3); 
    ADC->ADC_MR |= ADC_MR_STARTUP_SUT8; 
    ADC->ADC_EMR = 0; // TODO: Figure out this register
    return;
}

void PWM_Handler() {
    PWM->PWM_ISR1;
    AdcResult = ADC->ADC_CDR[7];            // Read the previous result
    ADC->ADC_CR |= ADC_CR_START;            // Begin the next ADC conversion. 
    PWMC_SetDutyCycle(PWM, channel, (uint16_t)map(AdcResult, 0, MAXADC, 0, MAXAMP));
    return;
}

void setupPWM(){
    uint32_t ulPin = 7;

    // PWM Startup code

    // Starts the PWM clocks. Required to enable PWM.
    pmc_enable_periph_clk(PWM_INTERFACE_ID);
    // We'll be using the main clock without any dividers. This allows us the highest resolution.
 
    // Some Arduino library code to help with determining the channel
    channel = g_APinDescription[ulPin].ulPWMChannel;
    
    // Setup PWM for this pin and complementary pin
    PIO_Configure(g_APinDescription[ulPin].pPort,
            g_APinDescription[ulPin].ulPinType,
            g_APinDescription[ulPin].ulPin | PIO_PC18,      // In addition to the pin enabled from this function,
            g_APinDescription[ulPin].ulPinConfiguration);   // also enable the complementary pin.
  
    // Configure the channel
    PWM->PWM_CH_NUM[0].PWM_CMR = 1;
    // Disable ul_channel (effective at the end of the current period)
    if ((PWM->PWM_SR & (1 << channel)) != 0) {
        PWM->PWM_DIS = 1 << channel;
        while ((PWM->PWM_SR & (1 << channel)) != 0);
    }
    // Configure ul_channel   
    PWM->PWM_CH_NUM[channel].PWM_CMR = PWM_CMR_DTE | PWM_CMR_CALG; // Enable Deadtime and center align

    // Deadtime value set
    PWM->PWM_CH_NUM[channel].PWM_DT = DEFAULTDEADTIME << PWM_DT_DTL_Pos | DEFAULTDEADTIME;
    // Period value set
    PWMC_SetPeriod(PWM, channel, DEFAULTPERIOD);
    PWMC_SetDutyCycle(PWM_INTERFACE, channel, DEFAULTDUTY);
    PWMC_EnableChannel(PWM_INTERFACE, channel);

    PWMC_EnableChannelIt(PWM, channel);
    NVIC_EnableIRQ(PWM_IRQn);

    g_pinStatus[ulPin] = (g_pinStatus[ulPin] & 0xF0) | PIN_STATUS_PWM;
    return;
}

void setDT(uint16_t dtTime){
    PWM->PWM_CH_NUM[channel].PWM_DTUPD = dtTime << 16 | dtTime;
    return;
}

// Shouldn't need this one
void setPeriod(uint16_t period){
    PWMC_SetPeriod(PWM, channel, period);
    return;
}

void setDuty(uint16_t duty){
    PWMC_SetDutyCycle(PWM, channel, duty);
    return;
}

void setup() {
  Serial.begin(115200);
  setupADC();
  setupPWM();
  amplitude = DEFAULTDUTY;
  deadtime = DEFAULTDEADTIME;
  sampleFreq = DEFAULTPERIOD;
  waveFreq = 0;
  waveType = flat;
  while(!Serial);
  Serial.println("ready");
}

void loop() {
    if(Serial.available() > 0){
        Serial.readBytesUntil(0, string, 100);
        if(!parseSerial(string, &amplitude, &deadtime, &sampleFreq, &waveType, &waveFreq)){
            sprintf(string, "Amplitude: %u Deadtime: %u", amplitude, deadtime);
            Serial.println(string);
            PWMC_DisableChannelIt(PWM, channel);
            NVIC_DisableIRQ(PWM_IRQn);
            setDuty(amplitude);
            setDT(deadtime);
        }
    }
}

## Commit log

2021-10-26 Added files for allAboutCircuits
    [ClassDAmplifier-555LM393IR2110-V3.kicad_pcb, ClassDAmplifier-555LM393IR2110.kicad_pcb, ClassDAmplifier-555LM393IR2110.sch]
2021-10-26 Added rough draft comparator circuit
2021-10-26 resister value changed 10000->10k
    changed resistor values to be easier to read and less confusing
2021-11-01 Added schematics for 555 timer
2021-11-06 12V 5V Circuit Simulation
    Complete Circuit is non functional too complex sub circuits functional
2021-11-10 Create Class_D_Amplifier_prototype_SDG3.pdf
    Changed Schematic to be more accurate with the author
2021-11-10 Added datasheet for IR2011 driver
2022-01-21 Create main.cpp
    PWM Tester for Due
2022-01-21 Added ADC functionality, fixed garbage serial input bug
    We may need to tweak the ADC sample frequency, I can't tell without lab equipment if it's set to a high enough frequency for audio.
    I've tested the ADC in with PWM out functionality using a potentiometer and LEDs and it's working as intended and demonstratable.
    serial garbage issue was when the Due would restart/reset, there would be garbage in the input buffer which would trigger the response to show the Amplitude/Deadtime output string but as garbled mess. Now the output message won't show unless there's a valid change made.
    [main.cpp]
2022-01-24 PWM Interrupt flag wasn't cleared
    This bug didn't show up til the last change I made and didn't test it before I pushed the change. I forgot to clear the status flag on the PWM interrupt. If forgotten, the PWM interrupt repeats without delay.
    [main.cpp]
2022-01-25 Rename main.cpp to main.ino
    So it opens in Arduino IDE.
2022-02-25 Updates
    - Created, updated, and deleted directories to appropriately organize files related to Happy Tunes
    - Updated README.md in repo root
    - Renamed several files to improve representation of their contents
    - Included .gitignore
    [ClassDAmplifier-555LM393IR2110-V3.kicad_pcb, ClassDAmplifier-555LM393IR2110.kicad_pcb, ClassDAmplifier-555LM393IR2110.sch]
2022-02-28 Hardware Readiness Material
    All items used within hardware readiness. Hardware 3d models created in Solidworks, PCB & Schematic within Hardware and LTSpice Simulations of Gate driver and level shifter
    [FacePlate.SLDPRT, FacePlateSheet.SLDDRW, GateDriver.SLDASM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]
2022-04-24 Current updates
2022-04-24 Added mapRange, rollingAverage, changed ranges of inputs.
    mapRange uses floating point math to map one range onto another. rollingAverage takes the last N many samples and averages them together to smooth out spikes.
    Changed the mapping ranges to amplify the ranges we'll be reading.
2022-04-29 Firmware with 10kHz filter
    Lots of debug code still here, will remove in next iteration.
